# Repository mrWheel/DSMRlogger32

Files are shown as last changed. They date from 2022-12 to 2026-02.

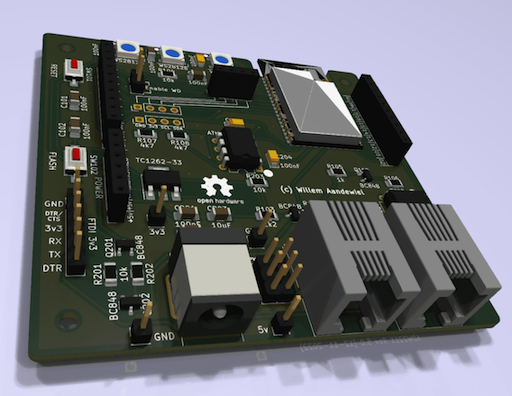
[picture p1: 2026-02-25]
DSMRlogger32/projectMetaData/DSMRlogger32.png

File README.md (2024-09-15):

# DSMRlogger32
Firmware for Rev. 5 of the DSMR-logger (Slimme Meter uitlezer)

This project is converted to VScode and PlatformIO.

# THIS IS A PRODUCTION RELEASE

This firmware is based on the **DSMRloggerAPI** (v3.0.4) firmware for the ESP8266 Micro Processor.

The **DSMRlogger32** firmware is for the **DSMR-logger32 Rev. 5** board with a ESP32 Micro Processor.

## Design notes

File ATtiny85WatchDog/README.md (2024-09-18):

# ATtiny85 Watch Dog for ESP8266/ESP32

## Overview

This project implements a watchdog functionality for any MCU using an ATtiny85 microcontroller. The watchdog monitors the main system (main MCU) for proper operation and can reset it if necessary.

## Hardware Configuration

The ATtiny85 is configured as follows:

```
ATMEL ATTINY85
                       +--\/--+
            RESET PB5 1|      |8 VCC
     <--[MCU_EN]  PB3 2|      |7 PB2  (INT0) <----- heartbeat
      [RESET_ME]  PB4 3|      |6 PB1  [x] 
                  GND 4|      |5 PB0  [NEO_LED] -> 
                       +------+
```

- PB0 (Pin 5): Connected to a NeoPixel LED for status indication
- PB2 (Pin 7): Receives heartbeat signals from the main system
- PB3 (Pin 2): Controls the main MCU's enable (reset) pin
- PB4 (Pin 3): Self-reset pin

## Programming

1.  First select [PROJECT TASKS] (the scary mask)
2.  Click on `set Fuses` (check that no errors occur)
3.  Now click on the [->] upload icon at the bottom of VSCode

## Functionality

The watchdog operates in several states, indicated by the NeoPixel LED:

1. **Power On**: Blue LED fades on and off for 30 seconds.
2. **Normal Operation**: Green LED heartbeat. Flashes bright when receiving heartbeat pulse from the main system.
3. **First Alarm**: Slow Red LED heartbeat if no heartbeats received for 60 seconds.
4. **Second Alarm**: Faster Red LED heartbeat if no heartbeats received for 75 seconds.
5. **Last Change**: Rapid Red LED blinking for 5 seconds before resetting the main system.
6. **Reset Master**: Bright White LED on while resetting the main system and waiting for it to restart.

## Key Features

- Uses interrupts to detect heartbeat signals from the main system.
- Implements a state machine for different levels of system monitoring.
- Utilizes a NeoPixel LED for visual status indication.
- Can reset both the main system MCU and itself if necessary.

## Configuration

The watchdog timing can be adjusted using the following constants:

- `_STARTUP_TIME`: 30 seconds
- `_MAX_NO_HARTBEAT`: 90 seconds (maximum time without a heartbeat before reset)
- `_LAST_WARNING`: 75 seconds (second alarm trigger)
- `_FIRST_WARNING`: 60 seconds (first alarm trigger)
- `_LAST_CHANGE`: 5 seconds (duration of last warning before reset)

## Usage

1. Connect the ATtiny85 to your main MCU system according to the pin configuration.
2. Program the ATtiny85 with this code.
3. Ensure your main system MCU sends regular heartbeat signals to the ATtiny85.
4. The watchdog will monitor your system and reset it if it becomes unresponsive.

## Dependencies

- EnableInterrupt library
- Custom NeoPixel library (neoPixStuff.h)

## License

This project is released under the MIT License. See the source code for full license text.

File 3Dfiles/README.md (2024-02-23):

# YAPP_Box
Yet Another Parametric Projectbox generator

This OpenSCAD project can be used to create extremely comprehensive and customizable project boxes/enclosures using OpenSCAD.

The [complete and official documentation gitbook](https://mrwheel-docs.gitbook.io/yappgenerator_en/) explains the entire API.

You can open Issues here, but please also place them in a comment at one of the following blog posts:
* "<a href="https://willem.aandewiel.nl/index.php/2022/01/02/yet-another-parametric-projectbox-generator/">Yet Another Parametric Projectbox generator blog post</a>" (English)
* "<a href="https://willem.aandewiel.nl/index.php/2022/01/01/nog-een-geparameteriseerde-projectbox-generator/">Nog een geparametriseerde projectbox generator</a>" (Dutch).

<hr>

I have done my best, but it can probably be done simpler. 
If you think you can help, please contact me or make a Pull Request.

## How to program your Project Box
It all starts with the dimensions of the PCB going inside your Project Box, as well as a few other dimensions:

```openscad
printBaseShell      = true;
printLidShell       = true;

// Edit these parameters for your own board dimensions
wallThickness       = 1.0;
basePlaneThickness  = 1.0;
lidPlaneThickness   = 1.0;

// Total height of box = basePlaneThickness + lidPlaneThickness 
//                     + baseWallHeight + lidWallHeight

baseWallHeight      = 7;
lidWallHeight       = 4;

pcbLength           = 88;
pcbWidth            = 49;
pcbThickness        = 1.5;
                            
// padding between pcb and inside wall
paddingFront        = 4;
paddingBack         = 1;
paddingRight        = 1;
paddingLeft         = 1;

// ridge where Base- and Lid- off the box can overlap
// Make sure this isn't less than lidWallHeight
ridgeHeight         = 3;
ridgeSlack          = 0.2;
roundRadius         = 2.0;  // don't make this to big..

//-- How much the PCB needs to be raised from the base
//-- to leave room for solderings and whatnot
standoffHeight      = 5.0;
pinDiameter         = 1.0;
pinHoleSlack        = 0.5;
standoffDiameter    = 4;
```

You probably want some cutouts in your box for connectors and stuff.
For every plane (side) of the Project Box, there is an array that holds the cutouts for that plane.

A picture is worth a thousand words ...

### Cutouts in the *Right* Plane:
YAPP_cutoutsRight

### Cutouts in the *Left* Plane:
YAPP_cutoutsLeft

### Cutouts in the *Back* Plane:
YAPP_cutoutsBack

### Cutouts in the *Front* Plane:
YAPP_cutoutsFront

### Cutouts in the *Base*:
YAPP_cutoutsBase

### Cutouts in the *Lid*:
YAPP_cutoutsLid

### Using the *angle* param (rotate around the x/y corner):
yappRectangle40dgrs

#### With `yappCenter`, the rectangle will rotate around its center point:
yappRectangleCenter10dgrs

### Base mounts:


### `pcbStands`:
`pcbStands` fixate the PCB between the base and the lid.
YAPP_pcbStands

### Connectors between *Base* and *Lid*:
YAPP_connectors

### ConnectorsPCB between *Base* and *Lid* that fixates the PCB:
connectorTypes

YAPP_connector_D

Inserts are great for making a screw connection between the base and the lid.
Ruthex-insert-a

### Snap Joins:
snapJoins1

snapJoins2

#### Snap Joins *Symmetrical*:
snapJoinsSymetric

### (more) Base Mounts:
yappBaseStand

yappBaseStand3D

### Hooks:
There are two type of "hooks"; at the inside of the box or at the outside of the box
#### `baseHookOutside()`:
baseHookOutside

baseHookOutside3D
#### `lidHookInside()`:
lidHooksInside1

lidHooksInside3Db

lidHooksInside3Da

<hr>

## Buy me a coffee (please)!

If you like this project or it saved you time, you can give me a cup of coffee :)

<p>
  <a href="https://www.paypal.me/WillemAandewiel/3">
      bmc-button-75
  </a>
</p>

## Versioning
* All major releases (v1, v2, v3) are intended to be compatible with all files previously designed for v3 (e.g., the v3.1 release will not remove features or make any breaking changes, compared to v3.0).
* The filename of the library (e.g., `YAPPgenerator_v3.scad`) will thus have only the major version in its filename.
* When a new major version is released, a branch will be created from the `main` branch at the last commit before work is started on the next major version. This branch can be used to fix bugs and add features to the old release version, if desired. These lineage branches will not be merged to `main`, and will continue on their own path.
* All future tagged versions will have GitHub Releases created for them, which will include the changelog for the release. The `YAPP_Template_vx.scad` and `YAPPgenerator_vx.scad` files will also be attached to the release.
* The ISO8601 international standard date format (yyyy-mm-dd) will be used for documenting dates.

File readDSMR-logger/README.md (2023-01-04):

# readDSMR-logger

Dit is een raamwerk om met verschillende MCU's de DSMRlogger32 uit te lezen en
de gegevens verder te verwerken.

Per board-type moet je één van onderstaande #define's actief maken door de twee 
slashes (//) ervoor weg te halen.
<pre>
//======= define type of board ===========
//==== only define one (1) board type ====
// #define _IS_ARDUINO_MEGA
// #define _IS_ESP8266
// #define _IS_ESP32
</pre>

### "myCredentials_org.h" 
Kopieer deze tab naar "myCredentials.h"

### In de tab "myCredentials.h" 
Define het IP address van jouw DSMR-logger:
<pre>
#define _DSMR_IP_ADDRESS    "IP_ADDRESS_OF_YOUR_DSMR_LOGGER"
</pre>

Als je een bordje met WiFi gebruikt voer dan hier de WiFi credentials van jouw AccessPoint in:
<pre>
#define _WIFI_SSID          "YOUR_WIFI_SSID"
#define _WIFI_PASSWRD       "YOUR_WIFI_PASSWRD"
</pre>

Dit programma vergt het maximale van een Arduino UNO met Ethernet shield!

Meer informatie over de DSMRlogger32 kun je 
<a href="https://willem.aandewiel.nl/index.php/2022/11/15/crisis-what-crisis/">hier</a>
vinden.

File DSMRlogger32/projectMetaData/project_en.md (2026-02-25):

# DSMRlogger32

This is an improved and more modern version of my earlier DSMR loggers (energy meter readers for smart meters).
Due to the energy crisis, it has become more important to monitor energy consumption closely. Therefore, after almost four years, I developed a new version.

The DSMRlogger32 offers the same basic functionality as the previous version, but operates more reliably and features improved memory management thanks to the ESP32 with PSRAM module. Some features from earlier versions have been removed (such as integration with mindergas.nl and an ADC interface), as they were considered non-essential.

New features include the ability to connect a shield with additional hardware (for example Modbus or relays), and a secondary P1 port for connecting an additional reader. In addition, a hardware watchdog has been added to prevent the system from locking up.

The project includes both hardware design and firmware, with improved support for JSON data and a more stable logging experience. PCBs or complete kits are available.

**Note!**
You can flash the firmware for the ESP32 here, but if you build the entire project yourself, please note that the ATtiny85 (watchdog) must also be flashed separately.

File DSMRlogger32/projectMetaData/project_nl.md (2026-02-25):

# DSMRlogger32

Dit is een verbeterde en modernere versie van mijn eerdere DSMR-loggers (energiemeteruitlezers voor slimme meters).
Door de energiecrisis is het belangrijker geworden om het energieverbruik goed bij te houden. Daarom heb ik na bijna vier jaar een nieuwe versie ontwikkeld.

De DSMRlogger32 biedt dezelfde basisfunctionaliteit als de vorige versie, maar werkt betrouwbaarder en beschikt over beter geheugenbeheer dankzij de ESP32 met PSRAM-module. Sommige functies uit eerdere versies zijn verwijderd (zoals integratie met mindergas.nl en een ADC-interface), omdat deze als niet-essentieel werden beschouwd.

Nieuwe kenmerken zijn onder andere de mogelijkheid om een shield met extra hardware aan te sluiten (bijvoorbeeld Modbus of relais), en een secundaire P1-poort om een extra uitlezer aan te sluiten. Daarnaast is een hardware-watchdog toegevoegd om vastlopen te voorkomen.

Het project omvat zowel hardwareontwerp als firmware, met verbeterde ondersteuning voor JSON-data en een stabielere loggingervaring. Er is de mogelijkheid om PCB’s of complete sets te verkrijgen.

Let op!
Je kunt hier de firmware voor de ESP32 flashen, maar als je het volledige project zelf bouwt, houd er dan rekening mee dat je de ATtiny85 (watchdog) ook zelf moet flashen.

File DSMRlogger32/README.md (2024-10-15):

# DSMRlogger32
Firmware for the DSMR-logger Rev. 5.0 using only API call's

[Here](https://willem.aandewiel.nl/index.php/2022/11/15/crisis-what-crisis/),
    [here](https://willem.aandewiel.nl/index.php/2019/04/09/dsmr-logger-v4-slimme-meter-uitlezer/) and
    [here](https://willem.aandewiel.nl/index.php/2020/02/28/restapis-zijn-hip-nieuwe-firmware-voor-de-dsmr-logger/)
          you can find information about this project.

Documentation can be found [here](https://mrwheel-docs.gitbook.io/dsmrlogger32/) (in progress)!

### Ported to PlatformIO
As of now the DSMRlogger32 firmware is ported to `VSCode` with the `PlatformIO` extension.
<p>

<table>
  <tr><th>Versie</th><th align="Left">Opmerking</th></tr>
  <tr>
    <td valign="top">5.4.2</td>
    <td>Nieuwe functionaliteit
        <br>2024-10-15: Add second relay on shield.<br>
        Ieder relay kan afzonderlijk binnen een tijdsframe worden in- en uitgeschakeld.<br>
        Het is het beste om zowel de firmware alsook SPIFFS te updaten.
    </td>
  </tr>
  <tr>
    <td valign="top">5.4.0</td>
    <td>Nieuwe functionaliteit
        <br>2024-10-03: Met deze update is het niet alleen mogelijk om firmware updates
        van de Remote Server te halen en te flashen maar ook het SPIFFS bestandsysteem
        kan nu via [Update Remote] worden geflashed.<br><br>
        Er is een nieuw soort presentatie met horizontale 'bars'. Dit is een voortborduring
        op de Gauges van HJM. Deze voldoen helaas niet bij installaties met zonnepanelen
        vandaar deze nieuwe functionaliteit. Je kunt deze zien door op het icoontje
        <big>&#9776</big> te klikken.<br>
        pwrBars
        <br><br>
        Om deze nieuwe update te kunnen gebruiken moet je éérst de firmware updaten en
        daarná het SPIFFS bestand systeem. Vergeet niet om je RING en `.json` bestanden
        te downloaden en na de update weer terug te zetten.
    </td>
  </tr>
  <tr>
    <td valign="top">5.3.0</td>
    <td>Nieuwe functionaliteit
        <br>2024-09-20: Firmware updates kunnen nu ook vanaf een remote server worden
        opgehaald. Als de functie wordt opgestart ([FSmanager]->[Update Remote])
        verschijnt er een scherm met een drop-down lijst met beschikbare updates.<br>
        Selecteer de gewenste update en klik op [Update] om de update uit te voeren
        of op [Return] om terug te keren naar de FSmanager.<br>
        Om deze nieuwe functionaliteit te kunnen gebruiken moet éénmalig de nieuwe
        firmware (versie 5.3.0) naar je lokale computer worden gedownload en daarna
        met [Update Local] worden geflashed.<br>
        Om deze functie te kunnen gebruiken moet, behalve de firmware update, ook
        het bestand `FSmanager.html` (te vinden op `github`) vanuit de data folder 
        worden gedownload naar je lokale computer en daarna met de FSmanager worden
         ge-[Upload].<br>
        Het uploaden van SPIFFS is helaas nog niet mogelijk.
    </td>
  </tr>
  <tr>
    <td valign="top">5.2.1</td>
    <td>Nieuwe functionaliteit
        <br>2024-09-16: Op een GPIO-pin kan (bijvoorbeeld) een relays worden aangesloten.
        Via de [Instellingen] -> [Systeem] kun je nu opgeven op welke GPIO-pin
        dit relays is aangesloten en bij welke waarden dit relays "Aan" of "Uit" moet 
        gaan. Om niet te snel na het "Uit" schakelen van het relays deze weer "Aan" 
        te zetten kan er een Hysterese Tijd worden ingesteld.<br>
        Ook kan de logica van de aansturing van het Relays ge-inverteerd
        worden (om te voorkomen dat het relays in rust, de "Uit stand", juist
        bekrachtigd wordt). Sommige relays modules maken gebruik van deze 
        inversed logic.
    </td>
  </tr>
  <tr>
    <td valign="top">5.0.5</td>
    <td>Nieuwe functionaliteit
        <br>24-04-2023: Uitbreiding "Actual Tabel" naar 500 punten.
        Hiervoor is ook DSMRgraphics.js aangepast
        <br>Het is nu mogelijk de DSMR-logger32 in zgn. "Access Point"
        mode op te starten. De DSMR-logger32 wordt dan zelf een Access
        Point waar je je computer of tablet aan kunt koppelen.
        <br>De GUI en telnet zijn daarna bereikbaar op IP Adres "192.168.4.1" of
        URL "DMSR-ESP32.local".
    </td>
  </tr>
  <tr>
    <td valign="top">5.0.4</td>
    <td>First Production Release
        <br>De API is aangepast en uitvoer ervan zal verschillen van die in de 
        DSMRloggerAPI firmware (Rev. 3).
    </td>
  </tr>
  <tr>
    <td valign="top">5.0.3</td>
    <td>Release Candidate
        <br>Mindergas functionaliteit is weggehaald, want hoort niet thuis in deze firmware.
        Je kunt eenvoudig met een los esp8266 bordje de gegevens uit deze DSMR-logger halen en
        naar 'mindergas' sturen.
        <br>De API is aangepast en uitvoer ervan zal verschillen van die in de 
        DSMRloggerAPI firmware (Rev. 3).
    </td>
  </tr>
  <tr>
    <td valign="top">5.0.0</td>
    <td>Not for production!
        <br>Deze firmware is bij-lange-na nog niet compleet of zelf "werkend"
        <br>Mindergas functionaliteit is weggehaald, want hoort niet thuis in deze firmware.
        Je kunt eenvoudig met een los esp8266 bordje de gegevens uit deze DSMR-logger halen en
        naar 'mindergas' sturen.
        <br>Waarschijnlijk wordt de API aangepast en zal dus verschillen van die in de 
        DSMRloggerAPI firmware (Rev. 3).
    </td>
  </tr>
</table>

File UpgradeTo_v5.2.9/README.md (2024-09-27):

# Upgrade DSMRlogger32 naar v5.2.9

Het programma `Upgrade_v5.2.9.py` wordt gebruikt om de firmware en het bestandssysteem van de DSMRlogger32 te *upgraden* naar **v5.2.9**.

## Waarom is dit nodig?

Vanaf **v5.2.9** (dat in feite een *dummy* versie is ter voorbereiding op **v5.3.0**) is het mogelijk om firmware-updates rechtstreeks van een **Remote Firmware Server** te verkrijgen. 

Dit heeft als voordeel dat je zelf geen ontwikkelomgeving hoeft op te zetten. De maintainer van de DSMRlogger32 zal de firmware-updates op zijn remote server plaatsen, waarna je jouw DSMRlogger32 eenvoudig kunt updaten.

Helaas zijn de firmwareversies van vóór v5.2.9 niet geschikt voor deze functionaliteit. Het is alleen mogelijk om de upgrade ***bedraad*** uit te voeren.
Vervolgens moet je eenmalig de stappen in deze handleiding volgen.

## Wat heb je nodig ##

Voor de upgrade heb je het programma `Upgrade_v5.2.9.py` nodig, dat is geschreven in Python. Als Python nog niet op je computer is geïnstalleerd, kun je het downloaden [via deze link](https://www.python.org/downloads/).

Daarnaast heb je een **FTDI**- of een **USB naar seriële**-kabel nodig om de DSMRlogger32 op je computer aan te sluiten. Er zijn verschillende kabels beschikbaar en de prijzen kunnen sterk variëren. Het is daarom verstandig om even onderzoek te doen naar welke kabel voor jou het meest geschikt is.

**Let er wél op dat het een bordje of kabel is voor 3.3 volt (3v3) anders kun je de DSMRlogger32 beschadigen.**
<table>
  <tr>
    <td></td>
    <td>FTDI kabel<br>Let erop dat de aansluitingen overeenkomen met die van de DSMRlogger32</td>
  </tr>
  <tr>
    <td>Kabel2 </td>
   <td>USB naar TTL-Seriële kabel<br>Vcc hoeft niet te worden aangesloten<br>Alleen GND, TX en RX aansluiten</td>
  </tr>
  <tr>
    <td>Kabel3 </td>
    <td>FTDI bordje<br>Let erop dat de aansluitingen overeenkomen met die van de DSMRlogger32</td>
  </tr>
</table>

Een FTDI **3v3** kabel of bordje is aanbevolen. Hiermee wordt de DSMRlogger32 automatisch in de juiste flash mode gezet door het programma `Upgrade_v5.2.9.py`. Als je een *FTDI*- of *USB naar TTL*-kabel gebruikt die dit niet automatisch doet, zoals *USB naar TTL*-kabels met drie of vier aansluitingen, kun je de volgende foutmelding krijgen:
```
DSMRlogger32_Flasher - INFO - Starting DSMRlogger32 flashing process on port: <COM PORT>>
DSMRlogger32_Flasher - INFO - Working directory: /Users/<you>/DSMRlogger32/UpgradeTo_v5.2.9
DSMRlogger32_Flasher - INFO - Executing esptool with arguments: /Users/<you>/esptool.py v4.5.1
Serial port <COM PORT>
Connecting......................................
A fatal error occurred: Failed to connect to ESP32: No serial data received.
For troubleshooting steps visit: https://docs.espressif.com/projects/esptool/en/latest/troubleshooting.html
returned non-zero exit status 2.
DSMRlogger32_Flasher - ERROR - Error flashing DSMRlogger32
DSMRlogger32_Flasher - INFO - DSMRlogger32 flashing process completed.
```
 Als je deze foutmelding krijgt, moet je handmatig de flash mode activeren door de knoppen op de DSMRlogger32 als volgt te gebruiken, voordat je het programma start:

1.  Druk op de [Flash] knop en hou deze ingedrukt
2.  Druk nu op de [Reset] knop en laat deze weer los
3.  Laat nu de [Flash] knop los.

Na deze stappen zou het programma de DSMRlogger32 moeten herkennen en starten met de firmware-upgrade.

## Hoe voer je de upgrade uit?

1. **Download het pakket**:
   - Download een **`.zip`** bestand van deze repository naar je computer of gebruik het volgende commando om de repository te *clonen*:
     ```bash
     git clone https://github.com/mrWheel/DSMRlogger32.git
     ```
   - Let op: alleen de map `UpgradeTo_v5.2.9` is relevant voor de upgrade.

2. **Volg deze stappen één voor één en in de juiste volgorde**:
   - Start de FSmanager (het icoon van het *Filing Cabinet*).
   - Download de drie `RING-bestanden` naar je computer.
   - Download eventueel het `DSMRdevSettings.json` bestand naar je computer.
   - Sluit de DSMRlogger32 nog niet aan op je computer.
   - Start een ***Command Window***.
   - Navigeer naar de map `UpgradeTo_v5.2.9` met het commando `cd`.
   - Voer het volgende commando in:
     ```bash
     python3 Upgrade_v5.2.9.py <COM PORT>
     ```
     Vervang `<COM PORT>` door de poort waarop de DSMRlogger32 is (of wordt) aangesloten.

     De uitvoer zou ongeveer als volgt moeten zijn:
```plaintext
python3 Upgrade_v5.2.9.py <COM PORT>
DSMRlogger32_Flasher - INFO - Starting DSMRlogger32 flashing process on port: <COM PORT>
...
DSMRlogger32_Flasher - INFO - Installing required packages...
Collecting esptool
  Downloading esptool-4.8.1.tar.gz (409 kB)
    ━━━━━━━━━━━━━━━━━━━━━━━━━━━━━━━━━━━━━━━━ 409.5/409.5 kB 2.1 MB/s eta 0:00:00
  Installing build dependencies ... done
  Getting requirements to build wheel ... done
  Preparing metadata (pyproject.toml) ... done
Collecting pyserial
  Using cached pyserial-3.5-py2.py3-none-any.whl.metadata (1.6 kB)
...
Using cached six-1.16.0-py2.py3-none-any.whl (11 kB)
Using cached pycparser-2.22-py3-none-any.whl (117 kB)
Building wheels for collected packages: esptool
  Building wheel for esptool (pyproject.toml) ... done
  Created wheel for esptool: filename=esptool-4.8.1-py3-none-any.whl size=534237 sha256=74561f52b0d9d75887e4777d962133ed23538191d27c84625cfc40554360ffcd
  Stored in directory: /Users/<you>>/Library/Caches/pip/wheels/0e/da/61/96ab0615cc87eb88b681fd147d47ec0c9954e1349e3ce19753
Successfully built esptool
Installing collected packages: reedsolo, pyserial, intelhex, bitarray, six, PyYAML, pycparser, bitstring, argcomplete, ecdsa, cffi, cryptography, esptool
Successfully installed PyYAML-6.0.2 argcomplete-3.5.0 bitarray-2.9.2 bitstring-4.2.3 cffi-1.17.1 cryptography-43.0.1 ecdsa-0.19.0 esptool-4.8.1 intelhex-2.3.0 pycparser-2.22 pyserial-3.5 reedsolo-1.7.0 six-1.16.0
...
2024-09-25 14:12:20,155 - DSMRlogger32_Flasher - ERROR - Error flashing DSMRlogger32: Command '...' returned non-zero exit status 2.
2024-09-25 14:12:20,155 - DSMRlogger32_Flasher - INFO - DSMRlogger32 flashing process completed.
```
     Het proces stopt hier omdat er geen communicatie met de DSMRlogger32 is.

   - Sluit nu de DSMRlogger32 aan op de gebruikte seriële poort.
   - Voer opnieuw het volgende commando in:
     ```bash
     python3 Upgrade_v5.2.9.py <COM PORT>
     ```
     De uitvoer zou er nu als volgt uit moeten zien:
```plaintext
python3 Upgrade_v5.2.9.py <COM PORT>
DSMRlogger32_Flasher - INFO - Starting DSMRlogger32 flashing process on port: <COM PORT>
...
DSMRlogger32_Flasher - INFO - Executing esptool with arguments: /Users/<you>/DSMRlogger32/UpgradeTo_v5.2.9/venv/bin/python -m esptool --chip esp32 --port <COM PORT> --baud 230400 --before default_reset --after hard_reset write_flash -z --flash_mode dio --flash_freq 80m --flash_size 4MB 0x1000 /Users/<you>/DSMRlogger32/UpgradeTo_v5.2.9/bootloader.bin 0x8000 /Users/<you>/DSMRlogger32/UpgradeTo_v5.2.9/partitions.bin 0x10000 /Users/<you>/DSMRlogger32/UpgradeTo_v5.2.9/firmware_v5.2.9.bin 0x310000 /Users/<you>/DSMRlogger32/UpgradeTo_v5.2.9/spiffs_v5.2.9.bin
esptool.py v4.5.1
Serial port <COM PORT>
Connecting....
Chip is ESP32-D0WD-V3 (revision v3.0)
Features: WiFi, BT, Dual Core, 240MHz, VRef calibration in efuse, Coding Scheme None
Crystal is 40MHz
MAC: 8c:4b:14:81:ff:e8
Uploading stub...
Running stub...
Stub running...
Changing baud rate to 230400
Changed.
Configuring flash size...
Flash will be erased from 0x00001000 to 0x00005fff...
Flash will be erased from 0x00008000 to 0x00008fff...
Flash will be erased from 0x00010000 to 0x0016efff...
Flash will be erased from 0x00310000 to 0x0038ffff...
Compressed 18992 bytes to 13110...
Wrote 18992 bytes (13110 compressed) at 0x00001000 in 0.9 seconds (effective 166.8 kbit/s)...
Hash of data verified.
Compressed 3072 bytes to 128...
Wrote 3072 bytes (128 compressed) at 0x00008000 in 0.1 seconds (effective 438.1 kbit/s)...
Hash of data verified.
Compressed 1436192 bytes to 884735...
Wrote 1436192 bytes (884735 compressed) at 0x00010000 in 43.4 seconds (effective 265.0 kbit/s)...
Hash of data verified.
Compressed 524288 bytes to 48967...
Wrote 524288 bytes (48967 compressed) at 0x00310000 in 4.1 seconds (effective 1014.0 kbit/s)...
Hash of data verified.

Leaving...
Hard resetting via RTS pin...
DSMRlogger32_Flasher - INFO - DSMRlogger32 flashed successfully!
DSMRlogger32_Flasher - INFO - DSMRlogger32 flashing process completed.
```
     De DSMRlogger32 zal nu opnieuw opstarten met de nieuwe firmware.

   - Upload de drie bewaarde `RING-bestanden`.
   - Upload eventueel het `DSMRdevSettings.json` bestand.
   - Reboot de DSMRlogger32.

## Controleer de nieuwe firmware

In de GUI kun je nu zien dat firmware versie v5.2.9 actief is.

GUI Versie

Om de nieuwe functionaliteit te testen, ga je terug naar de FSmanager.

FSmanager

Klik nu op de knop [Update Remote].<br>
In het scherm dat verschijnt, selecteer je de gewenste versie van de firmware.

Remote Update

(In dit geval **v5.3.0**), waarna je op [Update] klikt.

Wacht tot de DSMRlogger32 opnieuw is opgestart.

Wait a bit..

Controleer in de GUI of de juiste firmware nu actief is.

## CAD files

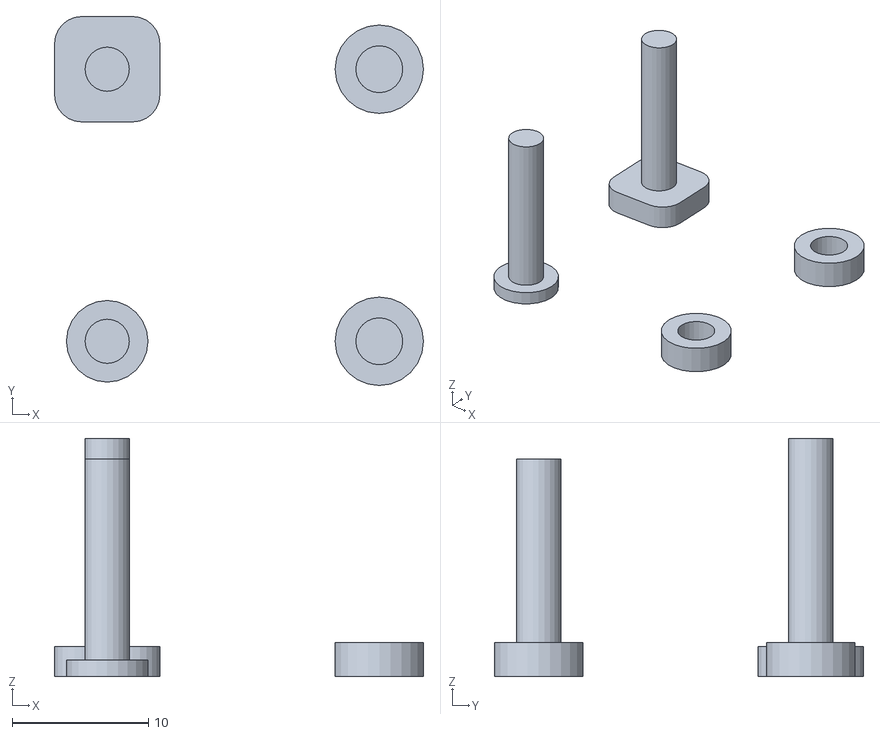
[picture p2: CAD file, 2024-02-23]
3Dfiles/STL/DSMR-logger32_R52_SwitchExtenders_v30.stl
27.1 x 27.1 x 17.5

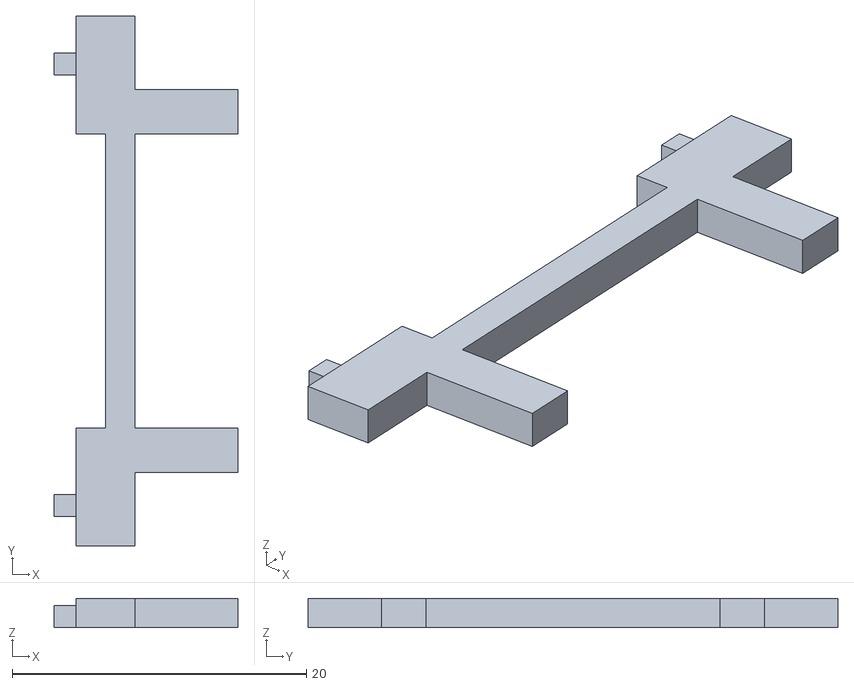
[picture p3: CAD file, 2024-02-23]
3Dfiles/STL/DSMR-logger32_R52_Stand_O13_v30.stl
12.5 x 36.0 x 2.00

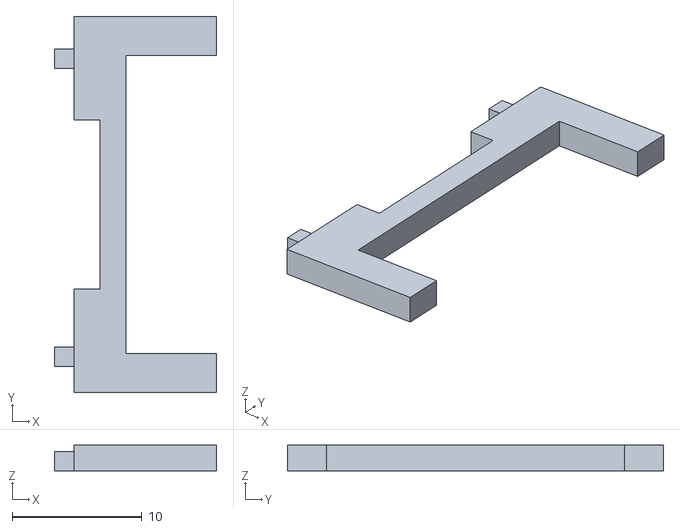
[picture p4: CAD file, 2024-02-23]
3Dfiles/STL/DSMR-logger32_R52_Stand_O09_v30.stl
12.5 x 29.0 x 2.00

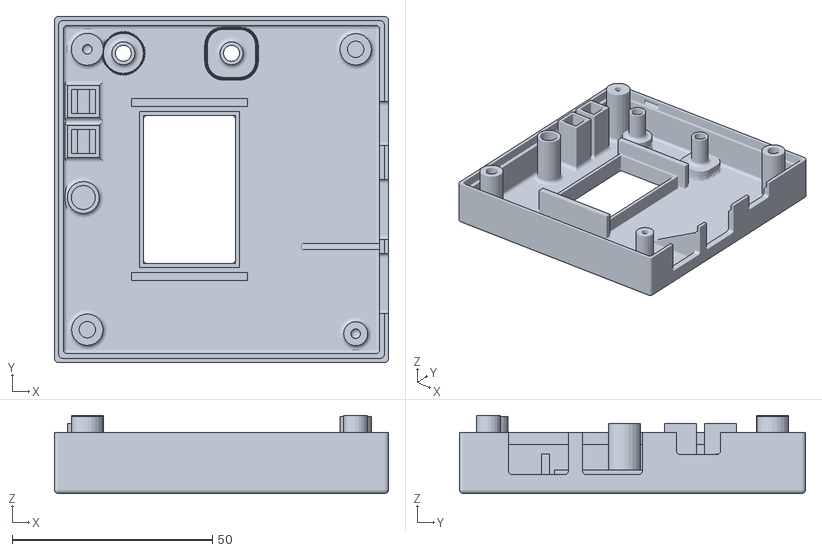
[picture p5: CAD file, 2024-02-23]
3Dfiles/STL/DSMR-logger32_R52_Top_O13_v30.stl
83.4 x 86.4 x 19.5

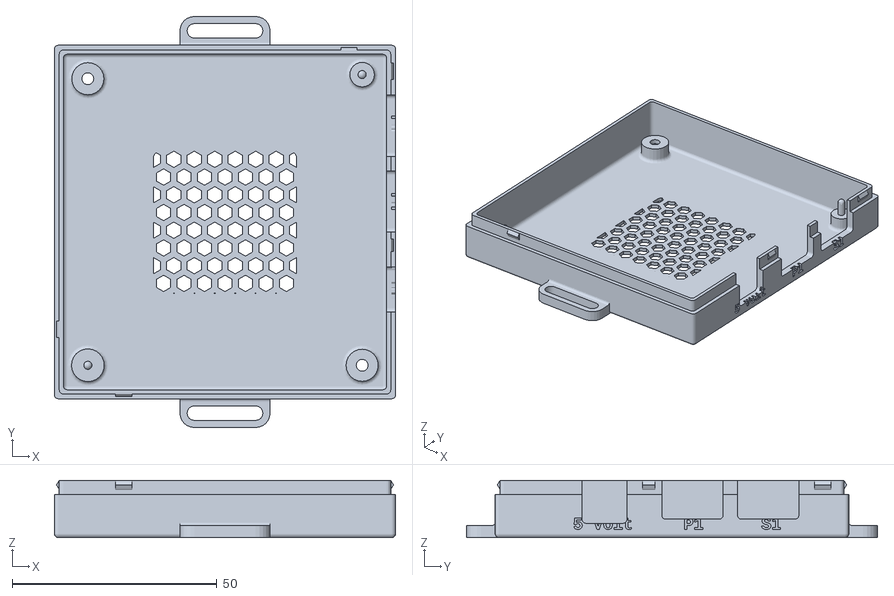
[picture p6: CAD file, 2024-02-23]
3Dfiles/STL/DSMR-logger32_R52_Base_v30.stl
83.4 x 100.4 x 14.0

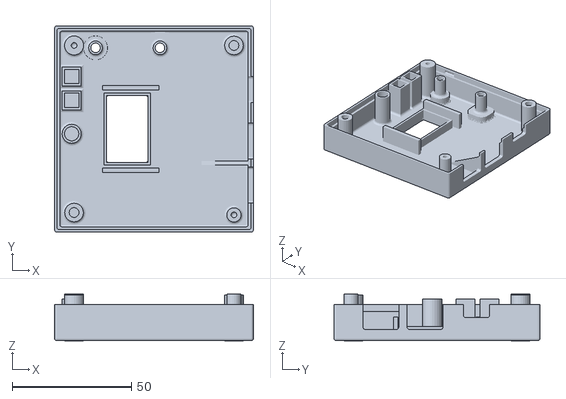
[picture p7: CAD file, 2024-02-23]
3Dfiles/STL/DSMR-logger32_R52_Top_O09_v30.stl
83.4 x 86.4 x 19.5

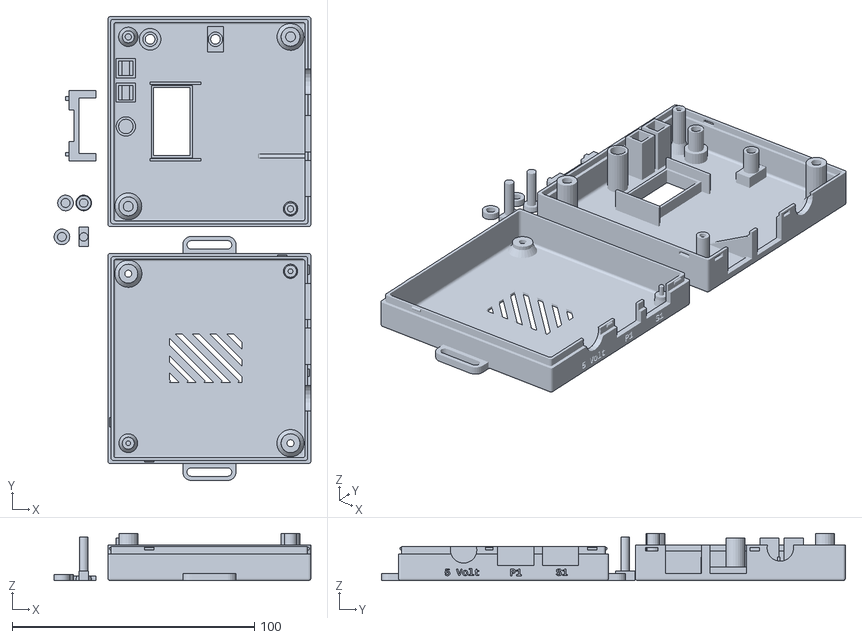
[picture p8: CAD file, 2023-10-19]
3Dfiles/STL/DSMR-logger32_R52_v20.stl
106.0 x 191.6 x 19.5

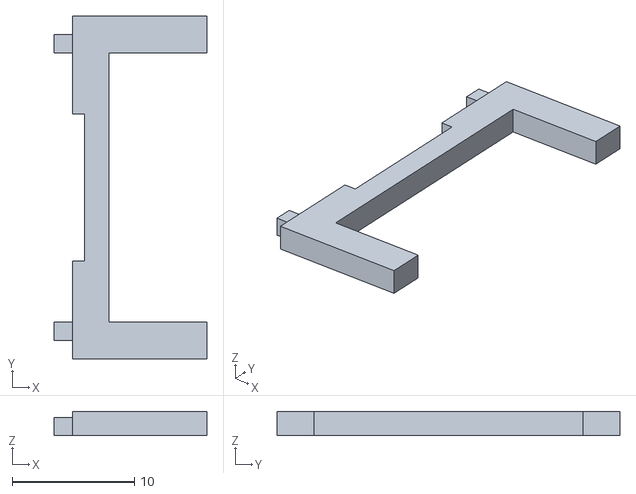
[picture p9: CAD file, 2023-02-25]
3Dfiles/STL/oled09Stand.stl
12.5 x 28.0 x 2.00

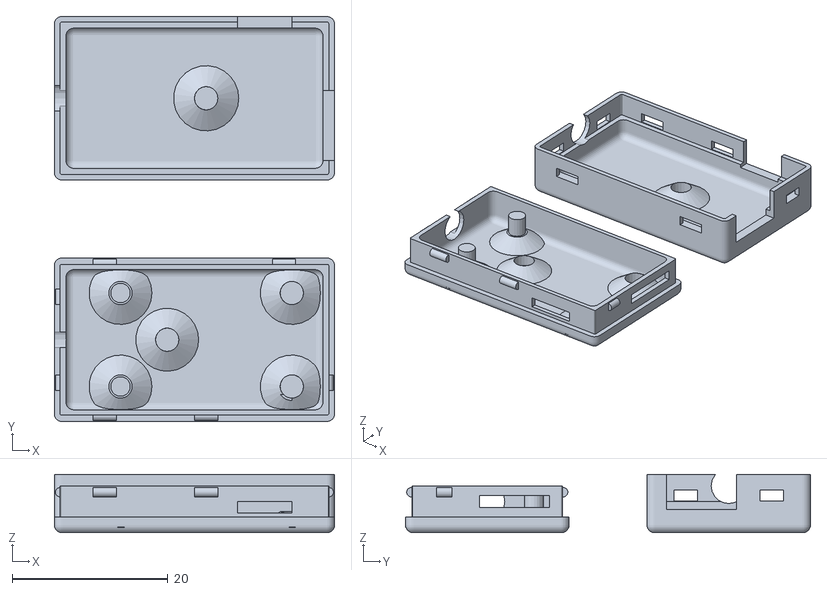
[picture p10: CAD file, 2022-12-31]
3Dfiles/STL/FTDIbox.stl
36.0 x 52.0 x 7.49

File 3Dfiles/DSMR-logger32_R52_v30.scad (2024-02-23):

//---------------------------------------------------------
// Yet Another Parameterized Projectbox generator
//
//  This is a box for a DSMR-logger32 v5.2 PCB
//  for use with the YAPP_generator_v30 lbrary
//
//  Version 3.0 (03-01-2024)
//
// This design is parameterized based on the size of a PCB.
//---------------------------------------------------------


//-- these parms need to be declared before including the YAPPgenerator
//
//-- is the filament transparent (true) or not (false)
//-- if (true) lightTubes will go all the way through the Lid
transparentFilament = true;  //-- {false|true}

//-- select oled size (both 'false' for none) -----
oled_09_inch          = false;
oled_13_inch          = true;

makeBaseShell        = false;
makeLidShell         = false;
makeSwitchExtenders  = false;
makeOledStand        = true;


if (oled_09_inch && oled_13_inch)
{
  for (i = [0 : 1 : 20])
  {
    echo("====================================");
    echo("Select (only one!) OLED screen size");
    echo("====================================");
  }
}
//
//- these dimensions are for a 1.3" OLED display
//-- oled dimensions and Header position
//                              //               V-------- HeaderY
oledHeader13X       = 16;       //       +~~~~~~~~~~~~~~~+            
oledHeader13Y       = 40;       //       |     ==o==     | HeaderX    ^
oledPcb13Width      = 37;       //       +---------------+ ScreenXs   |
oledPcb13Height     = 24;       //       |               |            |
oledScreen13Xs      =  3;       //       |               |            > Height
oledScreen13Xe      = 26;       //       |_______________|            |
                                //       +---------------+ ScreenXe   |
                                //       |               |            |
                                //       +---------------+            v
                                //       <--- Width ----->


//-- these dimensions are for a 0.9" OLED display
//-- oled dimensions and Header position
//                              //               V-------- HeaderY
oledHeader09X       = 17;       //       +~~~~~~~~~~~~~~~+            
oledHeader09Y       = 40;       //       |     ==o==     | HeaderX    ^
oledPcb09Width      = 28;       //       +---------------+ ScreenXs   |
oledPcb09Height     = 19;       //       |               |            |
oledScreen09Xs      =  1.5;     //       |               |            > Height
oledScreen09Xe      = 19.0;     //       |_______________|            |
                                //       +---------------+ ScreenXe   |
                                //       |               |            |
                                //       +---------------+            v
                                //       <--- Width ----->



oledScreen09Width  = oledPcb09Width;
oledScreen09Height = oledScreen09Xe - oledScreen09Xs;
oledScreen09X      = oledHeader09X + oledScreen09Xs;
oledScreen09Y      = oledHeader09Y - (oledScreen09Width/2);

oledScreen13Width  = oledPcb13Width;
oledScreen13Height = oledScreen13Xe - oledScreen13Xs;
oledScreen13X      = oledHeader13X + oledScreen13Xs;
oledScreen13Y      = oledHeader13Y - (oledScreen13Width/2);

//-- normalize params -----
oledHeaderX       = (oled_13_inch) ? oledHeader13X : oledHeader09X;
oledHeaderY       = (oled_13_inch) ? oledHeader13Y : oledHeader09Y;
oledScreenXs      = (oled_13_inch) ? oledScreen13Xs : oledScreen09Xs;
oledScreenXe      = (oled_13_inch) ? oledScreen13Xe : oledScreen09Xe;
oledScreenWidth   = (oled_13_inch) ? oledScreen13Width : oledScreen09Width;
oledScreenHeight  = (oled_13_inch) ? oledScreen13Height : oledScreen09Height;

oledRecess = (oled_09_inch || oled_13_inch) 
                      ? [oledScreenXs+oledHeaderX, oledHeaderY-(oledScreenWidth/2)
                         , oledScreenHeight, oledScreenWidth
                         , 1, -30003] //-> yappRoundedRect
                      : [];

lensThickness = (transparentFilament) ? 0.5 : 0;


include <./YAPPgenerator_v3.scad>

//include <./roundedCubes.scad>


/*
see https://polyd.com/en/conversione-step-to-stl-online
*/

myPcb = "./STL/MODELS/DSMR-logger32_MODEL_R52.stl";

if (true)
{
  translate([-47.3,-157.5,5.0]) 
  {
    rotate([0,0,90]) color("white") import(myPcb);
  }
}


// Note: length/lengte refers to X axis, 
//       width/breedte to Y, 
//       height/hoogte to Z

/*
      padding-back|<------pcb length --->|<padding-front
                            RIGHT
        0    X-as ---> 
        +----------------------------------------+   ---
        |                                        |    ^
        |                                        |   padding-right 
        |                                        |    v
        |    -5,y +----------------------+       |   ---              
 B    Y |         | 0,y              x,y |       |     ^              F
 A    - |         |                      |       |     |              R
 C    a |         |                      |       |     | pcb width    O
 K    s |         |                      |       |     |              N
        |         | 0,0              x,0 |       |     v              T
      ^ |   -5,0  +----------------------+       |   ---
      | |                                        |    padding-left
      0 +----------------------------------------+   ---
        0    X-as --->
                          LEFT
*/

printBaseShell        = makeBaseShell;
printLidShell         = makeLidShell;
printSwitchExtenders  = makeSwitchExtenders; 
//printInsideOLED       = makeInsideOled;  
printOledStand        = makeOledStand; 

// Edit these parameters for your own board dimensions
wallThickness       = 2.2; 
basePlaneThickness  = 1.0;
lidPlaneThickness   = 1.2;
// Set the ratio between the wall thickness and the ridge height. 
//    Recommended to be left at 1.8 but for strong snaps.
wallToRidgeRatio = 1.5;

//-- total height = 14 + pcbThickness + standoffHeight
//--         19.6 = 14 + 1.6 + 4
baseWallHeight      = 13; 
lidWallHeight       = 11; //-- was 8;

// ridge where base and lid off box can overlap
// Make sure this isn't less than lidWallHeight
ridgeHeight         = 3.5;
ridgeSlack          = 0.2;
roundRadius         = 1.0;

// How much the PCB needs to be raised from the base
// to leave room for solderings and whatnot
standoffHeight      = 4.0;  //-- only used to position PCB
standoffDiameter    = 5;
standoffPinDiameter = 2.0;
standoffHoleSlack   = 0.4;


// Total height of box = basePlaneThickness + lidPlaneThickness 
//                     + baseWallHeight + lidWallHeight
pcbLength           = 77;
pcbWidth            = 80;
pcbThickness        = 1.7;
                            
// padding between pcb and inside wall
paddingFront        = 1;
paddingBack         = 1;
paddingRight        = 1;
paddingLeft         = 1;


//---------------------------
//--     C O N T R O L     --
//---------------------------
// -- Render --
renderQuality             = 6;          //-> from 1 to 32, Default = 8
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

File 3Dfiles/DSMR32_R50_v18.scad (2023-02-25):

//---------------------------------------------------------
// Yet Another Parameterized Projectbox generator
//
//  This is a box for a DSMRlogger32 v5.x PCB
//
//  Version 1.0 (25-02-2023)
//
// This design is parameterized based on the size of a PCB.
//---------------------------------------------------------


//-- these parms need to be declared before including the YAPPgenerator

//-- default is 0.9" oled -----
oled_13_inch          = true;

//
//- these dimensions are for a 1.3" OLED display
//-- oled dimensions and Header position
//                              //               V-------- HeaderY
oledHeader13X       = 16;       //       +~~~~~~~~~~~~~~~+            
oledHeader13Y       = 40;       //       |     ==o==     | HeaderX    ^
oledPcb13Width      = 37;       //       +---------------+ ScreenXs   |
oledPcb13Height     = 24;       //       |               |            |
oledScreen13Xs      =  3;       //       |               |            > Height
oledScreen13Xe      = 26;       //       |_______________|            |
                                //       +---------------+ ScreenXe   |
                                //       |               |            |
                                //       +---------------+            v
                                //       <--- Width ----->


//-- these dimensions are for a 0.9" OLED display
//-- oled dimensions and Header position
//                              //               V-------- HeaderY
oledHeader09X       = 16;       //       +~~~~~~~~~~~~~~~+            
oledHeader09Y       = 40;       //       |     ==o==     | HeaderX    ^
oledPcb09Width      = 28;       //       +---------------+ ScreenXs   |
oledPcb09Height     = 19;       //       |               |            |
oledScreen09Xs      =  3;       //       |               |            > Height
oledScreen09Xe      = 16;       //       |_______________|            |
                                //       +---------------+ ScreenXe   |
                                //       |               |            |
                                //       +---------------+            v
                                //       <--- Width ----->



oledScreen09Width  = oledPcb09Width;
oledScreen09Height = oledScreen09Xe - oledScreen09Xs;
oledScreen09X      = oledHeader09X + oledScreen09Xs;
oledScreen09Y      = oledHeader09Y - (oledScreen09Width/2);

oledScreen13Width  = oledPcb13Width;
oledScreen13Height = oledScreen13Xe - oledScreen13Xs;
oledScreen13X      = oledHeader13X + oledScreen13Xs;
oledScreen13Y      = oledHeader13Y - (oledScreen13Width/2);

//-- normalize params -----
oledHeaderX       = (oled_13_inch) ? oledHeader13X : oledHeader09X;
oledHeaderY       = (oled_13_inch) ? oledHeader13Y : oledHeader09Y;
oledScreenXs      = (oled_13_inch) ? oledScreen13Xs : oledScreen09Xs;
oledScreenXe      = (oled_13_inch) ? oledScreen13Xe : oledScreen09Xe;
oledScreenWidth   = (oled_13_inch) ? oledScreen13Width : oledScreen09Width;
oledScreenHeight  = (oled_13_inch) ? oledScreen13Height : oledScreen09Height;

insertDiam  = 3.9;
screwDiam   = 2.7;
holeSlack   = 0.5;
insertDiamS = insertDiam + holeSlack;
screwDiamS  = screwDiam + holeSlack;


include <./YAPP_Box/library/YAPPgenerator_v18.scad>

include <./YAPP_Box/library/roundedCubes.scad>


/*
see https://polyd.com/en/conversione-step-to-stl-online
*/

myPcb = "./STL/DSMRloggerESP32_PCB_R50.stl";

if (false)
{
  translate([42,43,4.6]) 
  {
    rotate([0,0,90]) color("white") import(myPcb);
  }
}


// Note: length/lengte refers to X axis, 
//       width/breedte to Y, 
//       height/hoogte to Z

/*
      padding-back|<------pcb length --->|<padding-front
                            RIGHT
        0    X-as ---> 
        +----------------------------------------+   ---
        |                                        |    ^
        |                                        |   padding-right 
        |                                        |    v
        |    -5,y +----------------------+       |   ---              
 B    Y |         | 0,y              x,y |       |     ^              F
 A    - |         |                      |       |     |              R
 C    a |         |                      |       |     | pcb width    O
 K    s |         |                      |       |     |              N
        |         | 0,0              x,0 |       |     v              T
      ^ |   -5,0  +----------------------+       |   ---
      | |                                        |    padding-left
      0 +----------------------------------------+   ---
        0    X-as --->
                          LEFT
*/

printBaseShell        = false;
printLidShell         = false;
printSwitchExtenders  = false;
printInsideOLED       = false;
printOledStand        = true;
printSwitchCap        = false;

// Edit these parameters for your own board dimensions
wallThickness       = 2.4;
basePlaneThickness  = 1.0;
lidPlaneThickness   = 1.2;

//-- total height = 14 + pcbThickness + standoffHeight
//--         19.6 = 14 + 1.6 + 4
baseWallHeight      = 13; 
lidWallHeight       =  8;

// ridge where base and lid off box can overlap
// Make sure this isn't less than lidWallHeight
ridgeHeight         = 3;
ridgeSlack          = 0.2;
roundRadius         = 1.0;

// How much the PCB needs to be raised from the base
// to leave room for solderings and whatnot
standoffHeight      = 4.0;
pinDiameter         = 2.5;
pinHoleSlack        = 0.3;
standoffDiameter    = 6;

// Total height of box = basePlaneThickness + lidPlaneThickness 
//                     + baseWallHeight + lidWallHeight
pcbLength           = 77;
pcbWidth            = 80;
pcbThickness        = 1.6;
                            
// padding between pcb and inside wall
paddingFront        = 1;
paddingBack         = 1;
paddingRight        = 1;
paddingLeft         = 1;


//-- D E B U G -------------------
showSideBySide      = true;
hideLidWalls        = false;
onLidGap            = 0;
shiftLid            = 4;
colorLid            = "yellow";
hideBaseWalls       = false;
colorBase           = "white";
showOrientation     = true;
showPCB             = false;
showMarkers         = false;
inspectX            = 0;  // 0=none, >0 from front, <0 from back
inspectY            = 0;  // 0=none, >0 from left, <0 from right


//-- pcb_standoffs  -- origin is pcb[0,0,0]
// (0) = posx
// (1) = posy
// (2) = standoffHeight
// (3) = flangeHeight
// (4) = flangeDiam
// (5) = { yappBoth | yappLidOnly | yappBaseOnly }
// (6) = { yappHole, YappPin }
// (7) = { yappAllCorners | yappFrontLeft | yappFrondRight | yappBackLeft | yappBackRight }
pcbStands = [
            ];     

//-- Lid plane    -- origin is pcb[0,0,0]
// (0) = posx
// (1) = posy
// (2) = width
// (3) = length
// (4) = angle
// (5) = { yappRectangle | yappCircle }
// (6) = { yappCenter }
cutoutsLid =  [
      [14, 6,  6.5, 6.5, 0, yappCircle, yappCenter]         // Reset Button
     ,[41, 6,  8, 8, 0, yappRectangle, yappCenter]      // Flash Button
     //-- if no oled screen make next array a comment ---
     ,[oledScreenXs+oledHeaderX, oledHeaderY-(oledScreenWidth/2)
                        , oledScreenWidth, oledScreenHeight
                        , 0, yappRectangle]  // OLED
     ,[4, 18, 6, 6, 0, yappRectangle, yappCenter]       // NeoPixel 1
     ,[4, 28, 6, 6, 0, yappRectangle, yappCenter]       // NeoPixel 2
     ,[4, 40, 6, 6, 0, yappCircle]                      // NeoPixel 3
     ,[pcbLength-16, 40.5, 14, 18, 0,  yappRectangle]   // RJ12
     ,[pcbLength-16, 56.5, 14, 18, 0,  yappRectangle]   // RJ12
              ];

//-- base plane    -- origin is pcb[0,0,0]
// (0) = posx
// (1) = posy
// (2) = width
// (3) = length
// (4) = angle
// (5) = { yappRectangle | yappCircle }
// (6) = { yappCenter }
cutoutsBase =   [];

//-- cutoutGrills    -- origin is pcb[x0,y0,zx]
// (0) = xPos
// (1) = yPos
// (2) = grillWidth
// (3) = grillLength
// (4) = gWidth
// (5) = gSpace
// (6) = gAngle
// (7) = plane {"base" | "lid" }
// (8) = {polygon points}}

cutoutsGrill = [
                 [22, 30, 20, 30, 2, 3,  45, "base"]
               ];
              
//-- front plane  -- origin is pcb[0,0,0]
// (0) = posy
// (1) = posz
// (2) = width
// (3) = height
// (4) = angle
// (5) = { yappRectangle | yappCircle }
// (6) = { yappCenter }
cutoutsFront =  [
                    [40.5, -0.5, 14, 17, 0, yappRectangle]  // RJ11
                  , [56.5, -0.5, 14, 17, 0, yappRectangle]  // RJ11
                  , [24.5,  6,   12, 12, 0, yappCircle]     // PWR Jack

                ];

//-- back plane  -- origin is pcb[0,0,0]
// (0) = posy
// (1) = posz
// (2) = width
// (3) = height
// (4) = angle
// (5) = { yappRectangle | yappCircle }
// (6) = { yappCenter }
cutoutsBack =   [
                ];

//-- left plane   -- origin is pcb[0,0,0]
// (0) = posx
// (1) = posz
// (2) = width
// (3) = height
// (4) = angle
// (5) = { yappRectangle | yappCircle }
// (6) = { yappCenter }
cutoutsLeft =   [
                ];
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

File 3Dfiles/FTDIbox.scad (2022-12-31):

//-----------------------------------------------------------------------
// Yet Another Parameterized Projectbox generator
//
//  This is a box for FTDIbox
//
//  Version 1.1 (08-12-2022)
//
// This design is parameterized based on the size of a PCB.
//
//  for many or complex cutoutGrills you might need to adjust
//  the number of elements:
//
//      Preferences->Advanced->Turn of rendering at 100000 elements
//                                                  ^^^^^^
//
//-----------------------------------------------------------------------


include <../YAPP_Box/library/YAPPgenerator_v16.scad>

// Note: length/lengte refers to X axis, 
//       width/breedte to Y, 
//       height/hoogte to Z

/*
            padding-back>|<---- pcb length ---->|<padding-front
                                 RIGHT
                   0    X-ax ---> 
               +----------------------------------------+   ---
               |                                        |    ^
               |                                        |   padding-right 
             ^ |                                        |    v
             | |    -5,y +----------------------+       |   ---              
        B    Y |         | 0,y              x,y |       |     ^              F
        A    - |         |                      |       |     |              R
        C    a |         |                      |       |     | pcb width    O
        K    x |         |                      |       |     |              N
               |         | 0,0              x,0 |       |     v              T
               |   -5,0  +----------------------+       |   ---
               |                                        |    padding-left
             0 +----------------------------------------+   ---
               0    X-ax --->
                                 LEFT
*/

printBaseShell      = true;
printLidShell       = true;

// Edit these parameters for your own board dimensions
wallThickness       = 1.5;
basePlaneThickness  = 1.0;
lidPlaneThickness   = 1.0;

baseWallHeight      =  5;
lidWallHeight       =  3;

// ridge where base and lid off box can overlap
// Make sure this isn't less than lidWallHeight
ridgeHeight         = 4;
ridgeSlack          = 0.2;
roundRadius         = 1.0;

// How much the PCB needs to be raised from the base
// to leave room for solderings and whatnot
standoffHeight      = 0.5;
pinDiameter         = 2.5;
pinHoleSlack        = 0.3;
standoffDiameter    = 3;

// Total height of box = basePlaneThickness + lidPlaneThickness 
//                     + baseWallHeight + lidWallHeight
pcbLength           = 25;
pcbWidth            = 16;
pcbThickness        = 1.5;
                            
// padding between pcb and inside wall
paddingFront        = 3;
paddingBack         = 5;
paddingRight        = 1;
paddingLeft         = 1;


//-- D E B U G -------------------
showSideBySide      = true;
hideLidWalls        = false;
onLidGap            = 4;
shiftLid            = 0;
colorLid            = "yellow";
hideBaseWalls       = false;
colorBase           = "white";
showPCB             = false;
showMarkers         = false;
inspectX            = 0;  // 0=none, >0 from front, <0 from back
inspectY            = 0;  // 0=none, >0 from left, <0 from right


//-- pcb_standoffs  -- origin is pcb[0,0,0]
// (0) = posx
// (1) = posy
// (2) = { yappBoth | yappLidOnly | yappBaseOnly }
// (3) = { yappHole, YappPin }
pcbStands = [
                [ 2,  2, yappBaseOnly, yappPin] 
              , [ 2, 14, yappBaseOnly, yappPin] 
              , [ 8,  8, yappBaseOnly, yappHole] 
              , [24,  2, yappBaseOnly, yappHole] 
              , [24, 14, yappBaseOnly, yappHole] 
              , [13,  8, yappLidOnly,  yappHole] 
             ];     

//-- Lid plane    -- origin is pcb[0,0,0]
// (0) = posx
// (1) = posy
// (2) = width
// (3) = length
// (4) = angle
// (5) = { yappRectangle | yappCircle }
// (6) = { yappCenter }
cutoutsLid =  [
              ];

//-- base plane    -- origin is pcb[0,0,0]
// (0) = posx
// (1) = posy
// (2) = width
// (3) = length
// (4) = angle
// (5) = { yappRectangle | yappCircle }
// (6) = { yappCenter }
cutoutsBase =   [
                ];

//-- front plane  -- origin is pcb[0,0,0]
// (0) = posy
// (1) = posz
// (2) = width
// (3) = height
// (4) = angle
// (5) = { yappRectangle | yappCircle }
// (6) = { yappCenter }
cutoutsFront =  [
                    [11.5, -0.5, 9, 6, 0, yappRectangle, yappCenter]  // USB
                ];

//-- back plane  -- origin is pcb[0,0,0]
// (0) = posy
// (1) = posz
// (2) = width
// (3) = height
// (4) = angle
// (5) = { yappRectangle | yappCircle }
// (6) = { yappCenter }
cutoutsBack =   [
                  [8, 1, 4.5, 0, 0, yappCircle]      // cable
                ];

//-- left plane   -- origin is pcb[0,0,0]
// (0) = posx
// (1) = posz
// (2) = width
// (3) = height
// (4) = angle
// (5) = { yappRectangle | yappCircle }
// (6) = { yappCenter }
cutoutsLeft =   [
                    [17, -0.5, 7, 4, 0, yappRectangle]   // switch
                ];

//-- right plane   -- origin is pcb[0,0,0]
// (0) = posx
// (1) = posz
// (2) = width
// (3) = height
// (4) = angle
// (5) = { yappRectangle | yappCircle }
// (6) = { yappCenter }
cutoutsRight =  [
                ];

//-- cutoutGrills    -- origin is pcb[x0,y0, zx]
// (0) = xPos
// (1) = yPos
// (2) = grillWidth
// (3) = grillLength
// (4) = gWidth
// (5) = gSpace
// (6) = gAngle
// (7) = plane {"base" | "lid" }
// (8) = {polygon points}}

cutoutsGrill = [
               ];

//-- connectors -- origen = box[0,0,0]
// (0) = posx
// (1) = posy
// (2) = screwDiameter
// (3) = insertDiameter
// (4) = outsideDiameter
// (5) = { yappAllCorners }
connectors   =  [
                ];
                
//-- connectorsPCB -- origin = pcb[0,0,0]
//-- a connector that allows to screw base and lid together through holes in the PCB
// (0) = posx
// (1) = posy
// (2) = screwDiameter
// (3) = insertDiameter
// (4) = outsideDiameter
// (5) = { yappAllCorners }
connectorsPCB   =  [
                ];

//-- base mounts -- origen = box[x0,y0]
// (0) = posx | posy
// (1) = screwDiameter
// (2) = width
// (3) = height
// (4..7) = yappLeft / yappRight / yappFront / yappBack (one or more)
// (5) = { yappCenter }
baseMounts   = [
               ];
               
//-- snap Joins -- origen = box[x0,y0]
// (0) = posx | posy
// (1) = width
// (2..5) = yappLeft / yappRight / yappFront / yappBack (one or more)
// (n) = { yappSymmetric }
snapJoins   =     [
                    [5,  3, yappRight, yappSymmetric]
                  , [18, 3, yappLeft]
                  , [5,  3, yappLeft]
                  , [4,  2, yappFront]
                  , [4,  2, yappBack, yappSymmetric]
                ];
               
//-- origin of labels is box [0,0,0]
// (0) = posx
// (1) = posy/z
// (2) = orientation
// (3) = plane {lid | base | left | right | front | back }
// (4) = font
// (5) = size
// (6) = "label text"
labelsPlane =  [
                    [10,  10,   0, "lid",   "Liberation Mono:style=bold", 7, "YAPP" ]
               ];
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

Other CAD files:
3Dfiles/STL/DSMR-logger32_R52_Top_No_v30.stl
3Dfiles/roundedCubes.scad
3Dfiles/DSMR-logger32_R52_v20.scad
3Dfiles/YAPPgenerator_v20.scad
3Dfiles/YAPPgenerator_v3.scad

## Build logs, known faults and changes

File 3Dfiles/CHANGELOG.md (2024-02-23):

# YAPP Change Log

## Rev. v3.0.1 (2024-01-15)
* Re-organzie Git repo to maintain only the latest version in the `main` branch.
* The core files (`YAPP_Template_v3.scad`, `YAPPgenerator_v3.scad`) now keep only a major version in their filename, and live in the root of the repo.

## Rev. 3.0.0  (2023-12-01)

Lead Developer for v3.0: <a href="https://github.com/rosenhauer">Dave Rosenhauer</a>
Dave added new functionality, fixed many bugs, is the creator of the v3.0 API and did a lot of code cleanup.
He made more than 20 merge requests in three weeks.

**New functionality**
<pre>
Cutout Shapes
	Cutouts now support more shapes.
		yappRectangle	    : Rectangle with size 'width' x 'length' 
		yappCircle	    : Circle with radius of 'radius'
		yappRoundedRect	    : Rectangle with size 'width' x 'length' and corner 
                                      radius of 'radius'
		yappPolygon	    : User defined polygon. Three standard shapes are 
                                      included for use/reference - 'shapeIsoTriangle', 
                                      'shapeHexagon', 'shape6ptStar' 
		yappCircleWithFlats : Circle with radius of 'radius' with the sides 
                                      clipped to width (length is not used)
    		yappCircleWithKey   : Circle with radius of 'radius' with a rectangular 
                                      key of width x length (length is key depth)

Cutout Masks

Fillets
	Fillets are automatically added to all appropriate items.  
	This can be overridden with the yappNoFillet option.  
	Fillet radius can also be changed from default (same as connected wall thickness) 
	with the filletRadius parameter.

Ridge Extension
  Extension from the lid into the case for adding split opening at various heights

//========= HOOK dummy functions ============================
  
// Hook functions allow you to add 3d objects to the case.
// Lid/Base = Shell part to attach the object to.
// Inside/Outside = Join the object from the midpoint of the shell to the inside/outside.

//===========================================================
// origin = box(0,0,0)
module hookLidInside()
{
} // hookLidInside()
  
//===========================================================
// origin = box(0,0,shellHeight)
module hookLidOutside()
{
} // hookLidOutside()

//===========================================================
// origin = box(0,0,0)
module hookBaseInside()
{
} // hookBaseInside()

//===========================================================
// origin = box(0,0,0)
module hookBaseOutside()
{
} // hookBaseOutside()

//===========================================================
//===========================================================
</pre>

**Updated definition standards:**
<pre>
     Parameters:
	p(0,1 ...) = a 'p' with a number between parentheses indicates a 
	                    'positional' parameter.
	n(a,b ...) = a 'n' with a letter between parentheses indicates an 
	                    optional, 'non-positional' parameter must be after 
	                    the required parameters.
	{ yappParameter }
	&lt;Default value&gt;
	| means one or more values from the list are allowed
	, means only one value from the list is allowed
</pre>

**This version breaks with the API for the following objects:**

<pre>
===================================================================
  *** PCB Supports ***
  Pin and Socket standoffs 
-------------------------------------------------------------------
Default origin =  yappCoordPCB : pcb[0,0,0]

Parameters:
 Required:
  p(0) = posx
  p(1) = posy
 Optional:
  p(2) = Height to bottom of PCB : Default = defaultStandoffHeight
  p(3) = standoffDiameter    = defaultStandoffDiameter;
  p(4) = standoffPinDiameter = defaultStandoffPinDiameter;
  p(5) = standoffHoleSlack   = defaultStandoffHoleSlack;
  p(6) = filletRadius (0 = auto size)
  n(a) = { &lt;yappBoth&gt; | yappLidOnly | yappBaseOnly }
  n(b) = { &lt;yappPin&gt;, yappHole } : Baseplate support treatment
  n(c) = { &lt;yappAllCorners&gt; | yappFrontLeft | yappFrontRight | yappBackLeft | yappBackRight }
  n(d) = { &lt;yappCoordPCB&gt;, yappCoordBox }  
  n(e) = { yappNoFillet }
</pre>

<pre>
===================================================================
  *** Connectors ***
  Standoffs with hole through base and socket in lid for screw type connections.
-------------------------------------------------------------------
Default origin = yappCoordBox: box[0,0,0]
  
Parameters:
 Required:
  p(0) = posx
  p(1) = posy
  p(2) = pcbStandHeight
  p(3) = screwDiameter
  p(4) = screwHeadDiameter : (don't forget to add extra for the fillet)
  p(5) = insertDiameter
  p(6) = outsideDiameter
 Optional:
  p(7) = filletRadius : Default = 0/Auto(0 = auto size)
  n(a) = { &lt;yappAllCorners&gt; | yappFrontLeft | yappFrontRight | yappBackLeft | yappBackRight }
  n(b) = { &lt;yappCoordBox&gt;, yappCoordPCB }
  n(c) = { yappNoFillet }
</pre>

<pre>
===================================================================
  *** Base Mounts ***
  Mounting tabs on the outside of the box
-------------------------------------------------------------------
Default origin = yappCoordBox: box[0,0,0]

Parameters:
 Required:
  p(0) = pos
  p(1) = screwDiameter
  p(2) = width
  p(3) = height
 Optional:
  p(4) = filletRadius : Default = 0/Auto(0 = auto size)
  n(a) = { yappLeft | yappRight | yappFront | yappBack } : (one or more)
  n(b) = { yappNoFillet }
</pre>

<pre>
===================================================================
  *** Cutouts ***
  There are 6 cutouts one for each surface:
    cutoutsBase, cutoutsLid, cutoutsFront, cutoutsBack, cutoutsLeft, cutoutsRight
-------------------------------------------------------------------
Default origin = yappCoordBox: box[0,0,0]

                      Required                Not Used        Note
--------------------+-----------------------+---------------+------------------------------------
yappRectangle       | width, length         | radius        |
yappCircle          | radius                | width, length |
yappRoundedRect     | width, length, radius |               |     
yappCircleWithFlats | width, radius         | length        | length=distance between flats
yappCircleWithKey   | width, length, radius |               | width = key width length=key depth
yappPolygon         | width, length         | radius        | yappPolygonDef object must be provided
--------------------+-----------------------+---------------+------------------------------------

Parameters:
 Required:
  p(0) = from Back
  p(1) = from Left
  p(2) = width
  p(3) = length
  p(4) = radius
  p(5) = shape : {yappRectangle | yappCircle | yappPolygon | yappRoundedRect 
	         | yappCircleWithFlats | yappCircleWithKey}
 Optional:
  p(6) = depth : Default = 0/Auto : 0 = Auto (plane thickness)
  p(7) = angle : Default = 0
  n(a) = { yappPolygonDef } : Required if shape = yappPolygon specified -
  n(b) = { yappMaskDef } : If a yappMaskDef object is added it will be used as a mask for the cutout.
  n(c) = { &lt;yappCoordBox&gt;, yappCoordPCB }
  n(d) = { &lt;yappOrigin&gt;, yappCenter }
  n(e) = { &lt;yappGlobalOrigin&gt;, yappLeftOrigin } : Only affects Top, Back and Right Faces
</pre>

<pre>
===================================================================
  *** Snap Joins ***
-------------------------------------------------------------------
Default origin = yappCoordBox: box[0,0,0]

Parameters:
 Required:
  p(0) = posx | posy
  p(1) = width
  p(2) = { yappLeft | yappRight | yappFront | yappBack } : (one or more)
 Optional:
  n(a) = { &lt;yappOrigin&gt;, yappCenter }
  n(b) = { yappSymmetric }
  n(c) = { yappRectangle } == Make a diamond shape snap
</pre>

<pre>
===================================================================
  *** Light Tubes ***
-------------------------------------------------------------------
Default origin = yappCoordPCB: PCB[0,0,0]

Parameters:
 Required:
  p(0) = posx
  p(1) = posy
  p(2) = tubeLength
  p(3) = tubeWidth
  p(4) = tubeWall
  p(5) = gapAbovePcb
  p(6) = { yappCircle|yappRectangle } : tubeType
 Optional:
  p(7) = lensThickness : (how much to leave on the top of the lid for the light 
	 to shine through 0 for open hole, Default = 0/Open
  p(8) = Height to top of PCB : Default = defaultStandoffHeight+pcbThickness
  p(9) = filletRadius : Default = 0/Auto 
  n(a) = { &lt;yappCoordPCB&gt;, yappCoordBox }
  n(b) = { yappNoFillet }
</pre>

<pre>
===================================================================
  *** Push Buttons ***
-------------------------------------------------------------------
Default origin = yappCoordPCB: PCB[0,0,0]

Parameters:
 Required:
  p(0) = posx
  p(1) = posy
  p(2) = capLength for yappRectangle, capDiameter for yappCircle
  p(3) = capWidth for yappRectangle, not used for yappCircle
  p(4) = capAboveLid
  p(5) = switchHeight
  p(6) = switchTravel
  p(7) = poleDiameter
 Optional:
  p(8) = Height to top of PCB : Default = defaultStandoffHeight + pcbThickness
  p(9) = { &lt;yappRectangle&gt;, yappCircle } : buttonType, Default = yappRectangle
  p(10) = filletRadius : Default = 0/Auto 
</pre>

## Rev. 2.0  (21-05-2023)

**New functionality *lightTubes* **

With the **lightTubes** array you can define where you want tubes for LED's and NeoPixles**

<pre>
//-- lightTubes  -- origin is pcb[0,0,0]
// (0) = posx
// (1) = posy
// (2) = tubeLength
// (3) = tubeWidth
// (4) = tubeWall
// (5) = abovePcb
// (6) = tubeType  {yappCircle|yappRectangle}
lightTubes = [
              //--- 0,    1, 2, 3, 4, 5, 6
                  [84.5, 21, 3, 6, 1, 4, yappRectangle]
                , [30,   21, 5, 0, 1, 2, yappCircle]
              ];     
</pre>

lightTube_top
lightTube_a

<pre>
posx        - the position of the center of the led on the X-axes of the PCB
posy        - the position of the center of the led on the Y-axes of the PCB
tubeLength  - the length of the tube (if yappRectangle) or the diameter of the tube (if yappCircle)
tubeWidth   - the width of the tube (not used if yappCircle)
tubeWall    - the width of the wall around the led
abovePcp    - how hight the tube will begin with respect to the top of the PCB
tubeType    - whether the led shows as a circle (yappCircle) or a rectangle (yappRectangle)
</pre>

**New functionality *pushButtons* (experimental)**

With the **pushButtons** array you can define where you want button guides for tactile switches.</br>

<pre>
//-- pushButtons  -- origin is pcb[0,0,0]
// (0) = posx
// (1) = posy
// (2) = capLength
// (3) = capWidth
// (4) = capAboveLid
// (5) = switchHeight
// (6) = switchTrafel
// (7) = poleDiameter
// (8) = buttonType  {yappCircle|yappRectangle}
pushButtons = [
                 [15, 30, 8, 8, 0, 1,   1, 3.5, yappCircle]
               , [15, 10, 8, 6, 2, 4.5, 1, 3.5, yappRectangle]
              ];
</pre>

buttonGuides

The "Plate" has to be glued to the "Pole".

<pre>
posx         - the position of the center of the tacktile switch on the PCB
posy         - the position of the center of the tacktile switch on the PCB
capLength    - the length of the button (if yappRectangle) or the diameter (if yappCircle)
capWidth     - the width of the button (if yappRectangle, otherwise ignored)
capAboveLid  - how much the button cap is above the lid
switchHeight - the height of the tactile switch
switchTrafel - the distance the button has to trafel to activate the tacktile switch
poleDiameter - the diameter of the pole that connects the button cap with the plate
buttonType   - either yappCircle or yappRectangle
</pre>

<hr>

## Rev. 1.8  (22-02-2023)

**This version breaks with the API for the following array's:**

* pcbStand[..] (extra parameter for standoffHeight)
* connectors[..] (extra parameter for baseConnector Height)

<pre>
//-- pcb_standoffs  -- origin is pcb[0,0,0]
// (0) = posx
// (1) = posy
// (2) = standoffHeight
// (3) = flangeHeight
// (4) = flangeDiameter
// (5) = { yappBoth | yappLidOnly | yappBaseOnly }
// (6) = { yappHole, YappPin }
// (7) = { yappAllCorners | yappFrontLeft | yappFrontRight | yappBackLeft | yappBackRight }
pcbStands = [
                [3,  3, 5, 3, 11, yappBoth, yappPin, yappAllCorners]
               ,[5,  5, 5, 4, 10, yappBoth, yappPin, yappBackLeft, yappFrontRight]
               ,[8,  8, 5, 4, 11, yappBoth, yappPin]
               ,[pcbLength-15, pcbWidth-15, 8, 4, 12, yappBoth, yappPin]
             ];
</pre>
<pre>
//-- connectors
//-- normal         : origen = box[0,0,0]
//-- yappConnWithPCB: origen = pcb[0,0,0]
// (0) = posx
// (1) = posy
// (2) = pcbStandHeight
// (3) = screwDiameter
// (4) = screwHeadDiameter
// (5) = insertDiameter
// (6) = outsideDiameter
// (7) = flangeHeight
// (8) = flangeDiam
// (9) = { yappConnWithPCB }
// (10) = { yappAllCorners | yappFrontLeft | yappFrontRight | yappBackLeft | yappBackRight }
connectors   =  [
                    [ 8,  8, 5, 2.5, 2.8, 3.8, 6, 6, 15, yappAllCorners]
                  , [28, 58, 5, 2.5, 2.8, 3.8, 6, 6, 25, yappConnWithPCB]
                ];

</pre>

<hr>

## Rev. 1.7

**This version breaks with the API for the following array's:**

* pcbStand[..] (extra parameter for flange)
* connectors[..] (huge change lots of extra parameters)
* connectosPCB[..] (removed)

<pre>
//-- pcb_standoffs  -- origin is pcb[0,0,0]
// (0) = posx
// (1) = posy
// (2) = flangeHeight
// (3) = flangeDiameter
// (4) = { yappBoth | yappLidOnly | yappBaseOnly }
// (5) = { yappHole, YappPin }
// (6) = { yappAllCorners | yappFrontLeft | yappFrontRight | yappBackLeft | yappBackRight }
pcbStands = [
                [3,  3, 3, 11, yappBoth, yappPin, yappAllCorners]
               ,[5,  5, 4, 10, yappBoth, yappPin, yappBackLeft, yappFrontRight]
               ,[8,  8, 4, 11, yappBoth, yappPin]
               ,[pcbLength-15, pcbWidth-15, 4, 12, yappBoth, yappPin]
             ];
</pre>
<pre>
//-- connectors
//-- normal         : origen = box[0,0,0]
//-- yappConnWithPCB: origen = pcb[0,0,0]
// (0) = posx
// (1) = posy
// (2) = screwDiameter
// (3) = screwHeadDiameter
// (4) = insertDiameter
// (5) = outsideDiameter
// (6) = flangeHeight
// (7) = flangeDiam
// (8) = { yappConnWithPCB }
// (9) = { yappAllCorners | yappFrontLeft | yappFrontRight | yappBackLeft | yappBackRight }
connectors   =  [
                    [8, 8, 2.5, 2.8, 3.8, 6, 6, 15, yappAllCorners]
                  , [28, 58, 2.5, 2.8, 3.8, 6, 6, 25, yappConnWithPCB]
                ];

</pre>

The depth of the screw in the connectors is now depending on the standoffHeight so the
screw size does not change anymore.
YAPP_connectorRevised

<hr>

## Rev. 1.6

- new cutoutGrills array
<pre>
//-- cutoutGrills    -- origin is box[x0,y0]
// (0) = xPos
// (1) = yPos
// (2) = grillWidth
// (3) = grillLength
// (4) = gWidth
// (5) = gSpace
// (6) = gAngle
// (7) = plane [ "base" | "lid" ]
// (8) = {polygon points} (optional)

cutoutGrills = [
                 [22, 22, 90, 90, 2, 3, 50, "base", [  [0,15],[20,15],[30,0],[40,15],[60,15]
                                                      ,[50,30],[60,45], [40,45],[30,60]
                                                      ,[20,45], [0,45],[10,30] ]
                 ]
                ,[15, 10, 50, 10, 2, 3, -20, "base"]
                ,[15, 15, 10, 50, 2, 3, -45, "lid"]
                ,[15, 85, 50, 10, 2, 3,  20, "base"]
                ,[85, 15, 10, 50, 2, 3,  45, "lid"]
               ];
</pre>
cutoutGrills-v16

**Be aware**: this functionality needs a **huge** amount of rendering elements.

You can set this at `Preferences->Advanced->Turn of rendering at 100000 elements`
<hr>

## Rev. 1.5

- Various bug-fixes
- Connectors now have a flange at the basePlane and lidPlane for a better adhesion

*This release breaks with previous releases in the extra parm "**depth**" in the labels array!!*

The labels now have this syntax:
<pre>
//-- origin of labels is box [0,0,0]
// (0) = posx
// (1) = posy/z
// (2) = orientation
// (3) = depth
// (4) = plane {lid | base | left | right | front | back }
// (5) = font
// (6) = size
// (7) = "label text"
</pre>

Example:
<pre>
labelsPlane = [
                [10,  10,   0, 0.6, "lid",   "Liberation Mono:style=bold", 15, "YAPP" ]
               ,[100, 90, 180, 0.8, "base",  "Liberation Mono:style=bold", 11, "Base" ]
               ,[8,    8,   0, 1.0, "left",  "Liberation Mono:style=bold",  7, "Left" ]
               ,[10,   5,   0, 1.2, "right", "Liberation Mono:style=bold",  7, "Right" ]
               ,[40,  23,   0, 1.5, "front", "Liberation Mono:style=bold",  7, "Front" ]
               ,[5,    5,   0, 2.0, "back",  "Liberation Mono:style=bold",  8, "Back" ]
              ];
</pre>

For your box to work with this release as before you have to add this extra 
parm (as "wallThickness/2", "basePlaneThickness/2" or "lidPlaneThickness/2").

Thanks to *Keith Hadley*

There now is a new array for connectors that holds the PCB. This array is called "**connectorsPCB**".
<pre>
//-- connectorsPCB -- origin = pcb[0,0,0]
// (0) = posx
// (1) = posy
// (2) = screwDiameter
// (3) = insertDiameter
// (4) = outsideDiameter
// (5) = { yappAllCorners }
</pre>

Example:
<pre>
connectorsPCB = [
                  [pcbLength/2, 10, 2.5, 3.8, 5]
                 ,[pcbLength/2, pcbWidth-10, 2.5, 3.8, 5]
                ];
</pre>
It takes in account the "**pcbThickness**" to calculate the hight of the lid-connector.

Thanks to *Oliver Grafe*

connectorTypes

<hr>

## Rev. 1.4

*This release breaks with previous releases in the extra parm "**angle**" in all the cutouts array's!!!*

All plane array's now have this syntax:

<pre>
//-- plane    -- origin is pcb[0,0,0]
// (0) = posx
// (1) = posy
// (2) = width
// (3) = length
// (4) = angle
// (5) = { yappRectangle | yappCircle }
// (6) = { yappCenter }
</pre>

For your box to work with this release you have to add this extra parm (as "***0***") to all your cutOut-array-row's

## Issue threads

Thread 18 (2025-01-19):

zijn er plannen on watermeter ook uit te lezen?

PeterSchops, 2025-01-19:
In Belgie krijgen nieuwe installaties ook een watermeter, dus het leek me interessant om die ook mee te loggen.
Het zou gelijkaardig kunnen zijn als het gasverbruik.

mrWheel, 2025-01-20:
Als de water meter wordt aangesloten op de mBus van de Slimme Meter dan kun je dat gewoon in de GUI configureren.

PeterSchops, 2025-01-20:
De data wordt inderdaad reeds uitgelezen. Met als eenheid is GJ ipv m3.
Ik bedoelde echter of er plannen waren om die in het grafische overzicht op te nemen, om zo ook het waterverbruik op te volgen, per dag en per maand. Voor de moment gebruik ik de vorige versie met ESP8266, maar heb nieuwe hardware besteld om de nieuwe versie ook eens te proberen.

Name | Value | Unit
-- | -- | --
MBus-1 Gebruikt | 0.009 | m3
MBus-2 Gebruikt | 0.36 | GJ
MBus-3 Gebruikt | 0 | m3
MBus-4 Gebruikt | 0 | m3
Gas Gebruikt | 0.014 | m3

Als er geen plannen zijn, ga ik proberen om het zelf toe te voegen. Als ik het in kleine stappen doe, lijkt het iets wat doenbaar is. Eerst water waarden toevoegen in de ring-files, en hopelijk breekt dat het web gedeelte niet. En dan in een 2e stap de web pagina updaten.

mrWheel, 2025-01-21:
@PeterSchops,

Nee, ik heb voorlopig geen plannen om aanpassingen aan de firmware te doen.

Closed 2025-01-20.

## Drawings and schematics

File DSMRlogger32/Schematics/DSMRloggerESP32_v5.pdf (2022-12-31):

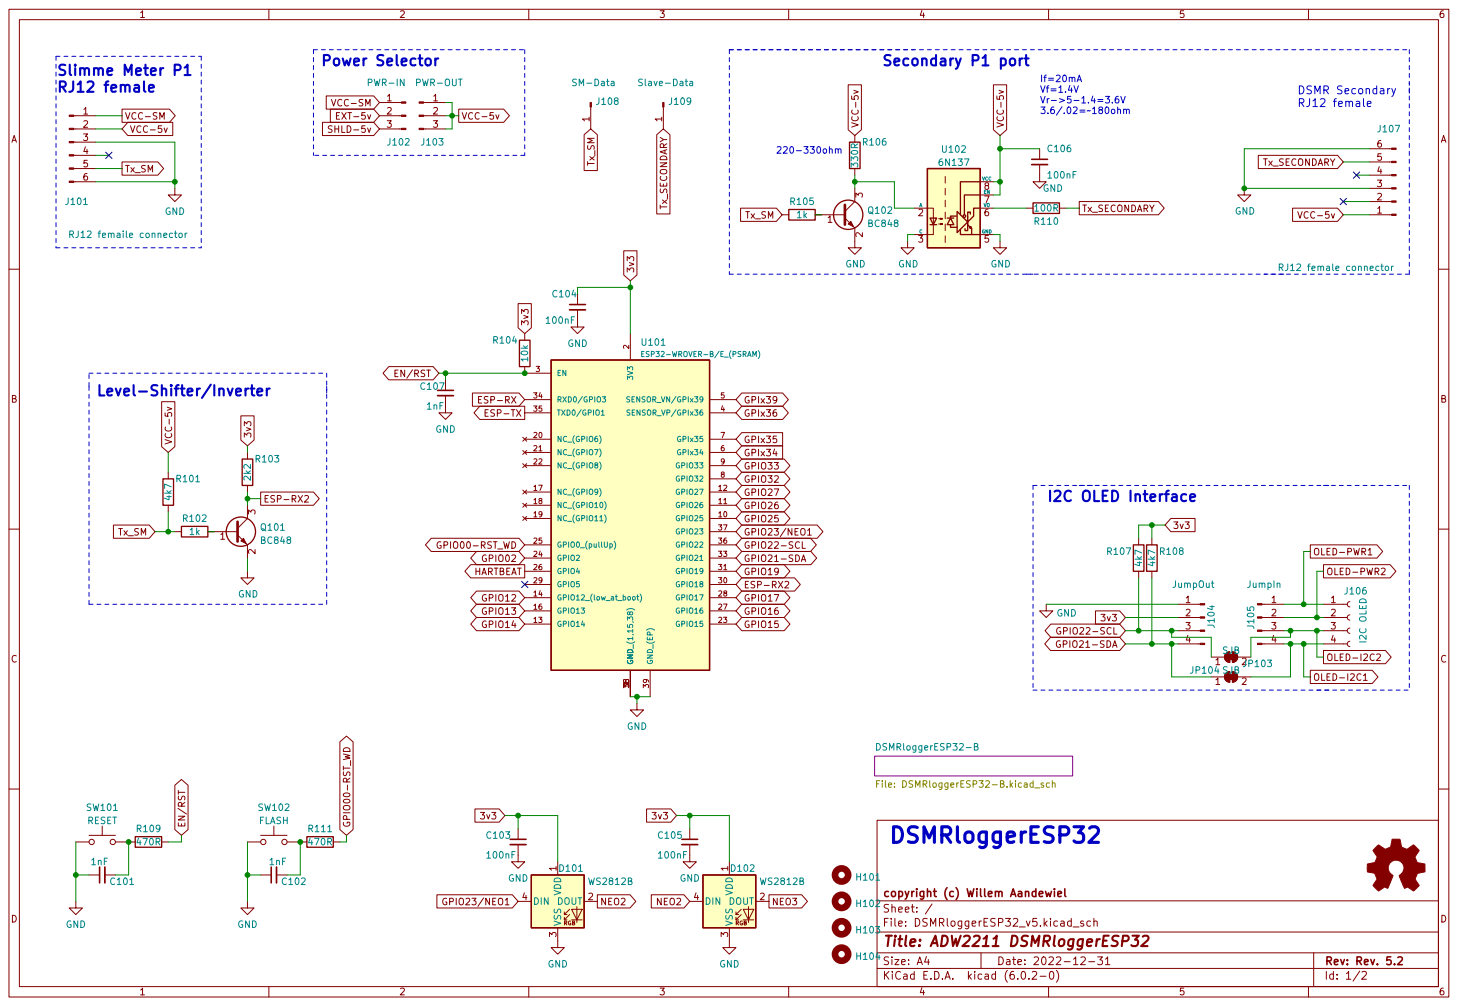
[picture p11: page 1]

2 NC_(GPIO6) 20 NC_(GPIO7) 21 NC_(GPIO8) 22 GPIO15 23 GPIO2 24 GPIO0_(pullUp) 25 GPIO4 26 GPIO16 27 GPIO17 28 GPIO5 29 EN 3 GPIO18 30 GPIO19 31 GPIO21 33 RXD0/GPIO3 34 TXD0/GPIO1 35 GPIO22 36 GPIO23 37 GND 38 GND_(EP) 39 SENSOR_VP/GPIx36 4 SENSOR_VN/GPIx39 5 GPIx34 6 GPIx35 7 GPIO32 8 GPIO33 9 U101

File: DSMRloggerESP32_v5.kicad_sch Sheet: / copyright (c) Willem Aandewiel

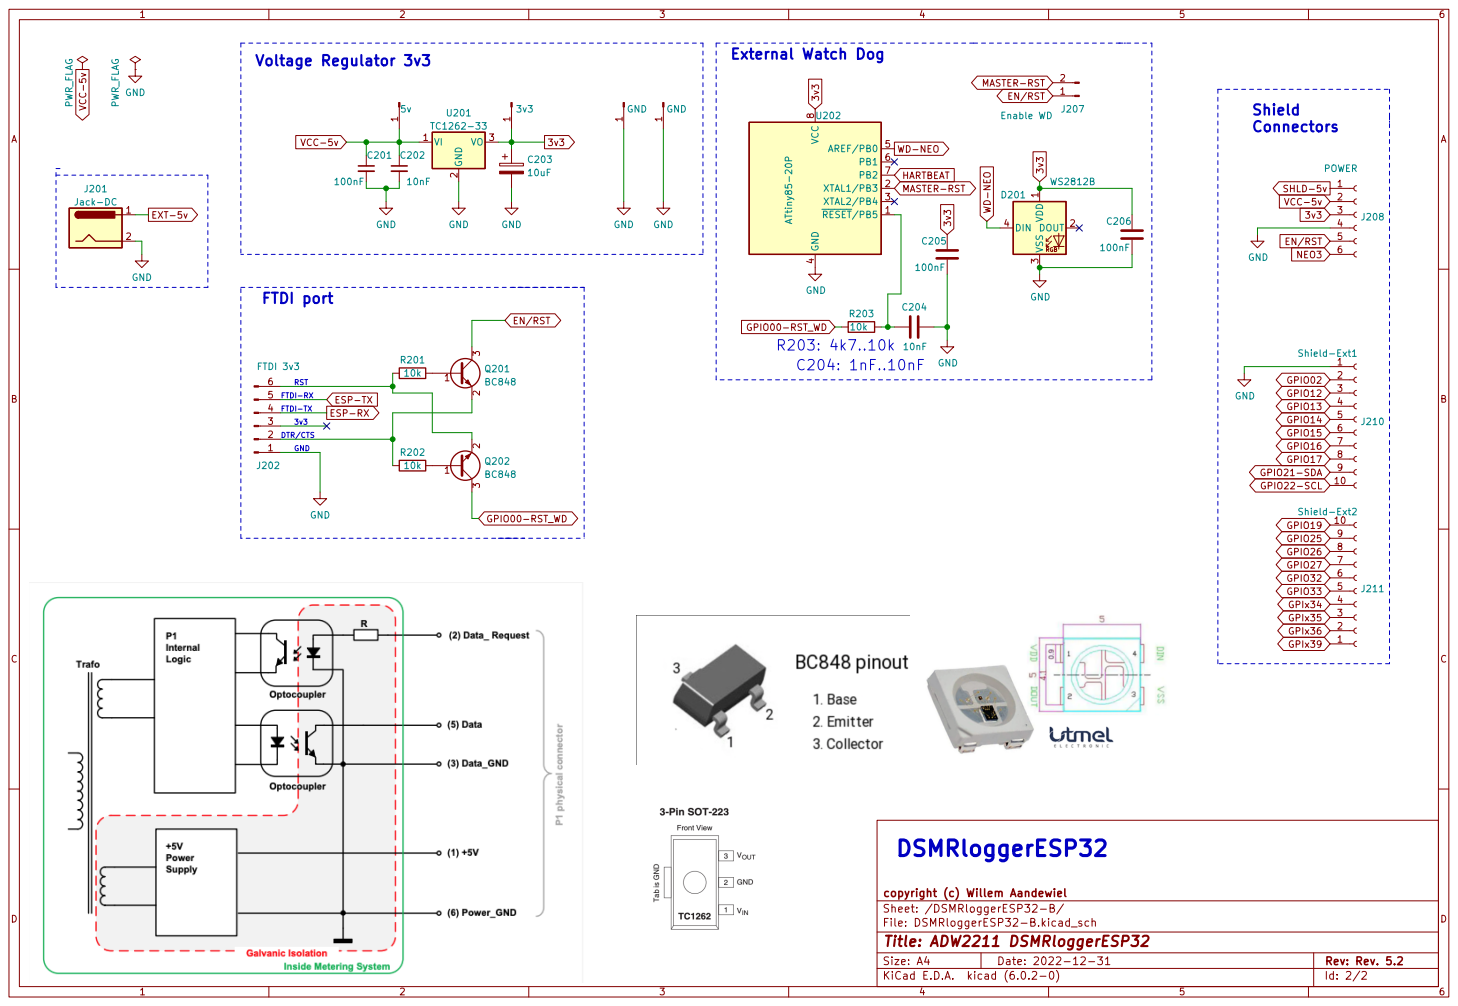
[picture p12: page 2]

FTDI-RX DTR/CTS FTDI port GND Voltage Regulator 3v3
Jack-DC PWR_FLAG GND

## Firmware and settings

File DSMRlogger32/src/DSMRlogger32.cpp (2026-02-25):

/*
***************************************************************************
**  Program  : DSMRlogger32 (restAPI)
*/
const char* PROG_VERSION = "v5.4.3 (25-02-2026)";
/*
**  Copyright (c) 2022, 2023, 2024 Willem Aandewiel
**
**  TERMS OF USE: MIT License. See bottom of file.
***************************************************************************
**
**  platformio.ini for DSMR-logger32 Revision 5 (ESP32): 
**
**    [platformio]
**    workspace_dir = .pio.nosync
**    default_envs = DSMRlogger32
**
**    [env:DSMRlogger32]
**    platform = espressif32
**    board = esp32dev
**    framework = arduino
**    ;board_build.partitions = min_spiffs.csv
**    ;board_build.partitions = huge_app.csv
**    board_build.partitions = ./partitions32.csv
**    board_build.filesystem = spiffs
**    board_build.flash_mode = qio
**    board_build.f_flash = 80000000
**    monitor_speed = 115200
**    upload_speed = 230400
**    ;-- change next line to your system
**    upload_port = /dev/cu.usbserial-3224142
**    build_flags = -w
**    ;      CORE_DEBUG_LEVEL: (0)NoLogging, (1)Error, (2)Warning, (3)Info, (4)Debug, (5)Verbose
**        -D CORE_DEBUG_LEVEL=3
**    	  -D BOARD_HAS_PSRAM
**    lib_ldf_mode = deep+
**    lib_deps =
**    	https://github.com/mrWheel/SPIFFS_SysLogger
**    	https://github.com/mrWheel/dsmr2Lib
**      https://github.com/mrWheel/TimeSyncLib
**    	greiman/SSD1306Ascii@^1.3.5
**    	jandrassy/TelnetStream@^1.3.0
**    	tzapu/WiFiManager@^2.0.17
**    	adafruit/Adafruit NeoPixel@^1.12.3
**      bblanchon/ArduinoJson@6.21.5
**    	knolleary/PubSubClient@^2.8
**    monitor_filters =
**    	esp32_exception_decoder

**
**  partition32.csv
**    # Name,   Type, SubType, Offset,  Size, Flags
**    nvs,      data, nvs,     0x9000,  0x5000,
**    otadata,  data, ota,     0xe000,  0x2000,
**    app0,     app,  ota_0,   0x10000, 0x180000,
**    app1,     app,  ota_1,   0x190000,0x180000,
**    spiffs,   data, spiffs,  0x310000,0x80000,
**
**  Coding Style  ( http://astyle.sourceforge.net/astyle.html#_Quick_Start )
**   - Allman style (-A1)
**   - tab 2 spaces (-s2)
**   - Indent 'switch' blocks (-S)
**   - Indent preprocessor blocks (-xW)
**   - Indent multi-line preprocessor definitions ending with a backslash (-w)
**   - Indent C++ comments beginning in column one (-Y)
**   - Insert space padding after commas (-xg)
**   - Attach a pointer or reference operator (-k3)
**
**  use:  astyle -A1 -s2 -S -xW -w -Y -xg- k3 *.{ino|h}
**
**  remove <filename>.orig afterwards
**
*/

/*
**  You can find more info in the following links (all in Dutch):
**   https://willem.aandewiel.nl/index.php/2020/02/28/restapis-zijn-hip-nieuwe-firmware-voor-de-dsmr-logger/
**   https://mrwheel-docs.gitbook.io/DSMRloggerAPI/
**   https://mrwheel.github.io/DSMRloggerWS/
**
**   https://mrwheel-docs.gitbook.io/DSMRlogger32/
*/

/******************** don't change anything below this comment **********************/

#include "DSMRlogger32.h"

//=======================================================================
float typecastValue(TimestampedFixedValue i)
{
  return strToFloat(String(i).c_str(), 3);
}

//=======================================================================
float typecastValue(FixedValue i)
{
  return i;
}

TimeSync timeSync; //-- new, not in Arduino version
struct tm timeinfo;
time_t now;

//===========================================================================================
void displayStatus()
{
  if (devSetting->OledType > 0)
  {
    switch (msgMode)
    {
    case 1:
    {
      memset(fChar, 0, _FCHAR_LEN);
      //----- PROG_VERSION format "vx.y.z (dd-mm-eeyy)"
      //-----                      012345  8901234567
      snprintf(fChar, _FCHAR_LEN, "%s", PROG_VERSION);
      int d = 0, s = 0;
      for (s = 0; s < 6; s++)
      {
        gMsg[d++] = fChar[s];
      }
      gMsg[d++] = ' ';
      gMsg[d++] = ' ';
      for (s = 8; s < 18; s++)
      {
        gMsg[d++] = fChar[s];
      }
      gMsg[d++] = 0;
      snprintf(gMsg, _GMSG_LEN, "%s", gMsg);
    }
    break;
    case 2:
      snprintf(gMsg, _GMSG_LEN, "Up:%-15.15s", upTime().c_str());
      break;
    case 3:
      if (runAPmode)
        snprintf(gMsg, _GMSG_LEN, "** ACCESS POINT **");
      else
        snprintf(gMsg, _GMSG_LEN, "WiFi RSSI:%4d dBm", WiFi.RSSI());
      break;
    case 4:
      if (runAPmode)
        snprintf(gMsg, _GMSG_LEN, "SSID: %s", devSetting->Hostname);
      else
      {
        if (WiFi.status() != WL_CONNECTED)
          snprintf(gMsg, _GMSG_LEN, "**** NO  WIFI ****");
        else
          snprintf(gMsg, _GMSG_LEN, "IP %s", WiFi.localIP().toString().c_str());
      }
      break;
    default:
      snprintf(gMsg, _GMSG_LEN, "Telgrms:%6d/%3d", telegramCount, telegramErrors);
      break;
    }

    oled_Print_Msg(3, gMsg, 0);
    //-- modular 5 = number of message displayed (hence it cycles thru the messages
    msgMode = (msgMode + 1) % 5;
  }
} // displayStatus()

//===========================================================================================
void setup()
{
  Serial.begin(115200);
  while (!Serial)
  {
    delay(10);
  }

  upTimeStart = millis() / 1000;

  neoPixels.begin();
  neoPixels.show();
  neoPixels.setBrightness(125);

  DebugTln("blink Neo Pixels ..");
  blinkNeoPixels(5, 750);
  neoPixOn(0, neoPixRed);
  neoPixOn(1, neoPixRed);

  // for now 115200. Look at end of setup()
  SMserial.begin(115200, SERIAL_8N1, SMRX, SMTX);

  Debugln("\n\n*******************************************************");
  Debugf("* Booting....[%s] \r\n", String(PROG_VERSION).c_str());
  Debugln("*******************************************************\r\n");
  DebugFlush();

  heap_caps_malloc_extmem_enable(_PSRAM_LIMIT);

  //-- claim PSRAM
  setupPsram();

  pinMode(LED_BUILTIN, OUTPUT);
  pinMode(_DTR_ENABLE, OUTPUT);
  pinMode(_FLASH_BUTTON, INPUT_PULLUP);
  pinMode(_PIN_HEARTBEAT, OUTPUT);
  pinMode(_PIN_WD_RESET, OUTPUT);

  //-- Hold WatchDog
  DebugTln("Reset Watchdog ..");
  resetWatchdog();

  pulseHeart(true);
  neoPixOn(0, neoPixRed);
  neoPixOff(1);

  runAPmode = !digitalRead(_FLASH_BUTTON);
  if (runAPmode)
    DebugTln("run in AP mode requested by user!");

  //------ initialize File System --------------------------
  setupFileSystem();

  //------ initialize devSetting logger --------------------
  setupSysLogger(PROG_VERSION);

  readDevSettings(true);
  readShieldSettings(true);

  if (devSetting->runAPmode > 0)
  {
    runAPmode = true;
    DebugTln("device setting: run as AP!");
  }
  oled_Init();

  //=============start Networkstuff==================================
  Serial.println(">>DSMR-logger32<<");
  Serial.println("Verbinden met WiFi...");

  if (devSetting->OledType > 0)
  {
    if (devSetting->OledFlip)
      oled_Init(); // only if true restart(init) oled screen
    oled_Clear();  // clear the screen
    oled_Print_Msg(0, ">>DSMR-logger32<<", 0);
    oled_Print_Msg(1, "Verbinden met WiFi", 500);
  }
  digitalWrite(LED_BUILTIN, LED_ON);
  if (!runAPmode)
  {
    startWiFi(devSetting->Hostname, 240, false); // timeout 4 minuten
    myWiFi.ipWiFi = WiFi.localIP();
    myWiFi.ipGateway = WiFi.gatewayIP();
    DebugT("DSMRlogger32 IP address: ");
    Debugln(WiFi.localIP());

    WiFi.onEvent(WiFiEvent);
  }
  else
  {
    if (devSetting->runAPmode)
      writeToSysLog("run in AP mode by system setting!");
    else
      writeToSysLog("run in AP mode requested by user!");
    WiFi.softAP(devSetting->Hostname);
    DebugT("AP IP address: ");
    Debugln(WiFi.softAPIP());
    lostWiFiConnection = false;
  }
  //--- setup randomseed the right way (??)
  //--- Read more: http://www.esp32learning.com/code/esp32-true-random-number-generator-example.php
  esp_random();

  if (devSetting->OledType > 0)
  {
    oled_Print_Msg(0, ">>DSMR-logger32<<", 0);
    if (runAPmode)
      oled_Print_Msg(1, devSetting->Hostname, 0);
    else
      oled_Print_Msg(1, WiFi.SSID(), 0);
    if (runAPmode)
      snprintf(gMsg, _GMSG_LEN, "IP %s", WiFi.softAPIP().toString().c_str());
    else
      snprintf(gMsg, _GMSG_LEN, "IP %s", WiFi.localIP().toString().c_str());
    oled_Print_Msg(2, gMsg, 1500);
  }

  startTelnet();
  if (devSetting->OledType > 0)
  {
    oled_Print_Msg(0, ">>DSMR-logger32<<", 0);
    oled_Print_Msg(3, "telnet (poort 23)", 2500);
  }

  digitalWrite(LED_BUILTIN, LED_OFF);

  Debugln();
  DebugT("Connected to ");
  if (runAPmode)
    Debugln(devSetting->Hostname);
  else
    Debugln(myWiFi.SSID);
  DebugT("IP address: ");
  if (runAPmode)
    Debugln(WiFi.softAPIP());
  else
    Debugln(myWiFi.ipWiFi);
  if (!runAPmode)
  {
    DebugT("IP gateway: ");
    Debugln(myWiFi.ipGateway);
  }
  Debugln();

  for (int L = 0; L < 4; L++)
  {
    digitalWrite(LED_BUILTIN, !digitalRead(LED_BUILTIN));
    delay(200);
  }
  digitalWrite(LED_BUILTIN, LED_OFF);

  startMDNS(devSetting->Hostname);
  if (devSetting->OledType > 0)
  {
    oled_Print_Msg(3, "mDNS gestart", 1500);
  }

  //=============end Networkstuff======================================

  //------ read status file for last Timestamp --------------------
  strlcpy(lastTlgrmTime.Timestamp, "040302010101X", _TIMESTAMP_LEN);
  //==========================================================//
  // writeLastStatus();  // only for firsttime initialization //
  //==========================================================//
  readLastStatus(); // place it in lastTlgrmTime.Timestamp

  DebugTf("last used time [%s]\r\n", lastTlgrmTime.Timestamp);

  //-- make sure both prev and last are initialized
  saveTimestamp(lastTlgrmTime.Timestamp);
  saveTimestamp(lastTlgrmTime.Timestamp);

  timeSync.setup();
  timeSync.sync(100);
  time(&now);
  DebugTf("===> lastTimestamp[%s]-> nrReboots[%u] - Errors[%u]\r\n\n", lastTlgrmTime.Timestamp, nrReboots++, slotErrors);

  readSmSettings(true);

  if (devSetting->OledType > 0)
  {
    oled_Init();
    oled_Clear(); // clear the screen so we can paint the menu.
    oled_Print_Msg(0, ">>DSMR-logger32<<", 0);
    int8_t sPos = String(PROG_VERSION).indexOf(' ');
    snprintf(gMsg, _GMSG_LEN, "(c)2022..2024 [%s]", String(PROG_VERSION).substring(0, sPos).c_str());
    oled_Print_Msg(1, gMsg, 0);
    oled_Print_Msg(2, " Willem Aandewiel", 0);
    oled_Print_Msg(3, " >> Have fun!! <<", 1000);
    yield();
  }
  else // don't blink if oled-screen attatched
  {
    for (int I = 0; I < 2; I++)
    {
      digitalWrite(LED_BUILTIN, !digitalRead(LED_BUILTIN));
      delay(250);
    }
  }
  digitalWrite(LED_BUILTIN, LED_OFF); // HIGH is OFF

  if (filesysMounted)
  {
    if (devSetting->OledType > 0)
    {
      oled_Print_Msg(0, ">>DSMR-logger32<<", 0);
      oled_Print_Msg(3, "Filesystm mounted", 1500);
    }
  }
  else
  {
    if (devSetting->OledType > 0)
    {
      oled_Print_Msg(0, ">>DSMR-logger32<<", 0);
      oled_Print_Msg(3, "MOUNT FS FAILED!", 2000);
    }
  }

  while (!psramFound())
  {
    DebugTln("*******************************************");
    DebugTln("**   This module does not have PSRAM!!   **");
    DebugTln("** Firmware will not run on this module! **");
    DebugTln("*******************************************\r\n");
    //-- send heartbeat for 2 minutes
    uint32_t waitTimer = millis();
    while ((millis() - waitTimer) < 120000)
    {
      pulseHeart();
      delay(10000);
    }
    DebugTln("No more heartbeats from now!\r\n");
    //-- now wait for Watchdog to reset this module
    while (1)
    {
      delay(1000);
    }
  }

  /**
    if (strlen(devSetting->Hostname) == 0)
    {
      snprintf(devSetting->Hostname, sizeof(devSetting->Hostname), "%s", _DEFAULT_HOSTNAME);
    }
  **/
  writeToSysLog("Hostname [%s]", devSetting->Hostname);
  //-- Press [Reset] -> "External System"
  //-- Software reset -> "Vbat power on reset"
  getLastResetReason(rtc_get_reset_reason(0), lastResetCPU0, 99);
  DebugTf("last Reset Reason CPU[0] - %s\r\n", lastResetCPU0);
  writeToSysLog("last Reset Reason CPU[0] - %s", lastResetCPU0);
  getLastResetReason(rtc_get_reset_reason(1), lastResetCPU1, 99);
  DebugTf("last Reset Reason CPU[1] - %s\r\n", lastResetCPU1);
  writeToSysLog("last Reset Reason CPU[1] - %s", lastResetCPU1);

  if (!runAPmode)
  {
    //================ startNTP =========================================
    if (devSetting->OledType > 0)
    {
      oled_Print_Msg(3, "setup NTP server", 100);
    }
    time(&now);
    DebugTln(F("NTP server set!\r\n\r"));
    DebugTf("NTP Date/Time: %02d-%02d-%04d %02d:%02d:%02d\r\n", localtime(&now)->tm_mday, localtime(&now)->tm_mon + 1, localtime(&now)->tm_year + 1900, localtime(&now)->tm_hour, localtime(&now)->tm_min, localtime(&now)->tm_sec);
    writeToSysLog("NTP Date/Time: %02d-%02d-%04d %02d:%02d:%02d", localtime(&now)->tm_mday, localtime(&now)->tm_mon + 1, localtime(&now)->tm_year + 1900, localtime(&now)->tm_hour, localtime(&now)->tm_min, localtime(&now)->tm_sec);

    if (devSetting->OledType > 0)
    {
      oled_Print_Msg(0, ">>DSMR-logger32<<", 0);
      oled_Print_Msg(3, "NTP gestart", 1500);
    }

    // if (timeSet) { ntpEventId = setEvent(logNtpTime, now()+3600); }

  } //-- !runAPmode

  //-- OK, WiFi connected, time set
  neoPixOn(0, neoPixGreen);

  //================ end NTP =========================================

  // writeToSysLog(lastReset);

  Serial.print("\nGebruik 'telnet ");
  if (runAPmode)
    Serial.print(WiFi.softAPIP());
  else
    Serial.print(WiFi.localIP());
  Serial.println("' voor verdere debugging\r\n");

  //=============now test if FS is correct populated!============
  filesysNotPopulated = setupIsFsPopulated();

  if (devSetting->OledType > 0)
  {
    snprintf(gMsg, _GMSG_LEN, "DT: %02d%02d%02d%02d0101x", thisYear, thisMonth, thisDay, thisHour);
    oled_Print_Msg(0, ">>DSMR-logger32<<", 0);
    oled_Print_Msg(3, gMsg, 1500);
  }

  //================ Start MQTT  ======================================

  connectMQTT();
  if (devSetting->OledType > 0)
  {
    oled_Print_Msg(0, ">>DSMR-logger32<<", 0);
    oled_Print_Msg(3, "MQTT server set!", 1500);
  }

  //================ Start HTTP Server ================================

  if (!filesysNotPopulated)
  {
    DebugTln(F("Filesystem correct populated -> normal operation!\r"));
    if (devSetting->OledType > 0)
    {
      oled_Print_Msg(0, ">>DSMR-logger32<<", 0);
      oled_Print_Msg(1, "OK, FS correct", 0);
      oled_Print_Msg(2, "Verder met normale", 0);
      oled_Print_Msg(3, "Verwerking ;-)", 2500);
    }
    if (hasAlternativeIndex)
    {
      httpServer.serveStatic("/", _FSYS, devSetting->IndexPage);
      httpServer.serveStatic("/index", _FSYS, devSetting->IndexPage);
      httpServer.serveStatic("/index.html", _FSYS, devSetting->IndexPage);
      httpServer.serveStatic("/DSMRindex.html", _FSYS, devSetting->IndexPage);
    }
    else
    {
      httpServer.serveStatic("/", _FSYS, "/DSMRindex.html");
      httpServer.serveStatic("/DSMRindex.html", _FSYS, "/DSMRindex.html");
      httpServer.serveStatic("/index", _FSYS, "/DSMRindex.html");
      httpServer.serveStatic("/index.html", _FSYS, "/DSMRindex.html");
      httpServer.serveStatic("/DSMRindex.css", _FSYS, "/DSMRindex.css");
      httpServer.serveStatic("/DSMRindex.js", _FSYS, "/DSMRindex.js");
      httpServer.serveStatic("/DSMRgraphics.js", _FSYS, "/DSMRgraphics.js");
    }
  }
  else
  {
    DebugTln(F("Oeps! not all files found on FS -> Start FSmanager!\r"));
    filesysNotPopulated = true;
    if (devSetting->OledType > 0)
    {
      oled_Print_Msg(0, "!OEPS! niet alle", 0);
      oled_Print_Msg(1, "files op FS", 0);
      oled_Print_Msg(2, "gevonden! (fout!)", 0);
      oled_Print_Msg(3, "Start FSmanager", 2000);
    }
    neoPixOn(1, neoPixRed);
  }

  setupFSmanager();

  httpServer.on("/api", HTTP_GET, processAPI);
  // all other api calls are catched in FSmanager onNotFounD!

  httpServer.begin();
  DebugTln("HTTP server gestart\r");
  if (devSetting->OledType > 0) // HAS_OLED
  {
    // HAS_OLED
    oled_Clear();                               // HAS_OLED
    oled_Print_Msg(0, ">>DSMR-logger32<<", 0);  // HAS_OLED
    oled_Print_Msg(2, "HTTP server ..", 0);     // HAS_OLED
    oled_Print_Msg(3, "gestart (poort 80)", 0); // HAS_OLED
  }

  httpUpdater.setup(&httpServer);

  //================ Start HTTP Server ================================

  DebugTf("Startup complete! lastTlgrmTime[%s]\r\n", lastTlgrmTime.Timestamp);
  writeToSysLog("Startup complete! lastTlgrmTime[%s]", lastTlgrmTime.Timestamp);

  if (devSetting->OledType > 0)
  {
    oled_Print_Msg(0, ">>DSMR-logger32<<", 0);
    oled_Print_Msg(1, "Startup complete", 0);
    oled_Print_Msg(2, "Wait for first", 0);
    oled_Print_Msg(3, "telegram .....", 500);
  }

  //================ Start Shield =====================================
  relay0.setup(shieldSetting[0]->GPIOpin, shieldSetting[0]->inversed, shieldSetting[0]->activeStart, shieldSetting[0]->activeStop, shieldSetting[0]->onThreshold, shieldSetting[0]->offThreshold, shieldSetting[0]->onDelay, shieldSetting[0]->offDelay);
  relay1.setup(shieldSetting[1]->GPIOpin, shieldSetting[1]->inversed, shieldSetting[1]->activeStart, shieldSetting[1]->activeStop, shieldSetting[1]->onThreshold, shieldSetting[1]->offThreshold, shieldSetting[1]->onDelay, shieldSetting[1]->offDelay);

  //================ Start Slimme Meter ===============================

  DebugTln(F("Enable slimmeMeter..\r"));

  DebugTln("Setup serial port for Smart Meter reading");
  if (smSetting->PreDSMR40 == 0)
  {
    DebugTf("SMserial is set to 115200 baud / 8N1 (RX=%d, TX=%d)\r\n", SMRX, SMTX);
    DebugFlush();
    SMserial.end();
    delay(100);
    SMserial.begin(115200, SERIAL_8N1, SMRX, SMTX);
    slimmeMeter.doChecksum(true);
  }
  else
  {
    // PRE40
    DebugTf("SMserial is set to 9600 baud / 7E1 (RX=%d, TX=%d)\r\n", SMRX, SMTX);
    DebugFlush();
    SMserial.end();
    delay(100);
    SMserial.begin(9600, SERIAL_7E1, SMRX, SMTX);
    slimmeMeter.doChecksum(false);
  }

  neoPixOn(1, neoPixGreenLow);

  updatedRINGfiles = false;

  delay(100);
  slimmeMeter.enable(true);

  DebugTln("reached end of setup()!");

} // setup()

//===[ no-blocking delay with running background tasks in ms ]============================
DECLARE_TIMER_MS(timer_delay_ms, 1);
void delayms(unsigned long delay_ms)
{
  CHANGE_INTERVAL_MS(timer_delay_ms, delay_ms);
  RESTART_TIMER(timer_delay_ms);
  while (!DUE(timer_delay_ms))
  {
    doSystemTasks();
  }

} // delayms()
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
void loop()
{
  //--- do the tasks that has to be done
  //--- as often as possible
  doSystemTasks();
  doTaskTelegram();
  doTaskShield();

  loopCount++;

  //--- if an OLED screen attached, display the status
  if (devSetting->OledType > 0)
  {
    if (DUE(updateDisplay))
    {
      displayStatus();
    }
  }

  //--- if connection lost, try to reconnect to WiFi
  if (lostWiFiConnection)
  {
    neoPixOn(0, neoPixRed);
    if (firstConnectionLost)
    {
      // writeToSysLog("Watchdog timer reset ...");
      firstConnectionLost = false;
      resetWatchdog();
    }

    glowTimer0 = millis() + 2000;
    if ((lostWiFiCount % 25) == 0)
    {
      DebugTf("Reconnect wifi with [%s]...\r\n", devSetting->Hostname);
      writeToSysLog("Reconnect wifi with [%s]...", devSetting->Hostname);
    }
    WiFi.disconnect();
    // WiFi.reconnect();
    delay(1000);
    WiFi.begin(myWiFi.SSID, myWiFi.password);
    delay(1000);
    if (WiFi.status() != WL_CONNECTED)
    {
      if (lostWiFiConnection && (lostWiFiCount % 25) == 0)
      {
        DebugTln("Wifi still not connected!");
        writeToSysLog("Wifi still not connected!");
      }
    }
    else
    {
      snprintf(gMsg, _GMSG_LEN, "IP:[%s], Gateway:[%s]", WiFi.localIP().toString().c_str(), WiFi.gatewayIP().toString().c_str());
      DebugTf("%s\r\n", gMsg);
      writeToSysLog("%s", gMsg);
      startMDNS(devSetting->Hostname);
    }
  } //  lostWiFiConnection
  else
  {
    //-- set NEO 0 to Green
    if ((millis() - glowTimer0) > _GLOW_TIME)
    {
      neoPixOn(0, neoPixGreenLow);
    }
  }

  yield();

} // loop()

/***************************************************************************
 *
 * Permission is hereby granted, free of charge, to any person obtaining a
 * copy of this software and associated documentation files (the
 * "Software"), to deal in the Software without restriction, including
 * without limitation the rights to use, copy, modify, merge, publish,
 * distribute, sublicense, and/or sell copies of the Software, and to permit
 * persons to whom the Software is furnished to do so, subject to the
 * following conditions:
 *
 * The above copyright notice and this permission notice shall be included
 * in all copies or substantial portions of the Software.
 *
 * THE SOFTWARE IS PROVIDED "AS IS", WITHOUT WARRANTY OF ANY KIND, EXPRESS
 * OR IMPLIED, INCLUDING BUT NOT LIMITED TO THE WARRANTIES OF
 * MERCHANTABILITY, FITNESS FOR A PARTICULAR PURPOSE AND NONINFRINGEMENT.
 * IN NO EVENT SHALL THE AUTHORS OR COPYRIGHT HOLDERS BE LIABLE FOR ANY
 * CLAIM, DAMAGES OR OTHER LIABILITY, WHETHER IN AN ACTION OF CONTRACT, TORT
 * OR OTHERWISE, ARISING FROM, OUT OF OR IN CONNECTION WITH THE SOFTWARE OR
 * THE USE OR OTHER DEALINGS IN THE SOFTWARE.
 *
 ***************************************************************************/

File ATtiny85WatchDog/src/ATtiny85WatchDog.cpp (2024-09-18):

/*
** ATtiny85 Watch Dog for an ESP8266/ESP32 or any other MCU
** 
** Copyright 2022 .. 2024 Willem Aandewiel
** Version 3.1  (18-09-2024)
** 
** Use [PROJECT TASKS] to set fuses (as in 'platformio.ini'):
**   - High Fuse: Serial program downloading (SPI) enabled
**   - High Fuse: Brown-out detector triggel level: Brown-out detection at VCC=1.8 V
**   - Low Fuse:  Select Clock Source: Int. RC Osc. 8 MHz; Start-up time PWRDWN/RESET: 6 CK/14 CK + 64 ms
**  
**      Low       : 0xE2
**      High      : 0xDE (but 0xDF might also "work" --> brown-out detection disabled)
**      Extended  : 0xFF
**
** ATMEL ATTINY85
**                        +--\/--+
**             RESET PB5 1|      |8 VCC
**    <--[ESP32_EN]  PB3 2|      |7 PB2  (INT0) <----- heartbeat
**       [RESET_ME]  PB4 3|      |6 PB1  [x] 
**                   GND 4|      |5 PB0  [NEO_LED] -> 
**                        +------+
**
**  Boot sequence:
**  ==============
**  State        | NEOPIXEL                | Remark
**  -------------+-------------------------+--------------------------------------
**  Power On     | BLUE                    | Fade On ~6 sec, fade Off 6 sec 
**               |                         | (duration: _STARTUP_TIME seconds) 
**               |                         | Next: "Normal Operation"
**  -------------+-------------------------+--------------------------------------
**  Normal       | GREEN HeartBeat         | Fade On ~5 sec, fade Off ~5 sec
**  Operation    |      while heartbeats   | 
**               |      received           | Next: "Normal Operation"
**               |                         |  
**               | if no Heartbeats        |  
**               |   for _FIRST_WARNING    |
**               |   seconds               | Next: "First Alarm"
**  -------------+-------------------------+--------------------------------------
**  First Alarm  | RED Heartbeat           | Fade On ~ 1.5sec, fade Off ~ 1.5 sec
**               |                         |  
**               | if Heartbeat received   | Next: "Normal Operation"                        |  
**               |                         |  
**               | if no Heartbeats        |  
**               |   for _LAST_WARNING     |
**               |   seconds               | Next: "Second Alarm"
**  -------------+-------------------------+--------------------------------------
**  Second Alarm | RED Heartbeat           | Fade On ~1 sec, fade Off ~1 sec
**               |                         |  
**               | if Heartbeat received   | Next: "Normal Operation"                        |  
**               |                         |  
**               | if no Heartbeats        |  
**               |   for _MAX_NO_HARTBEAT  |
**               |   seconds               | Next: "Last Change"
**  -------------+-------------------------+--------------------------------------
**  Last Change  | RED blink               | Blink On ~ 100mS, Off ~ 100mS
**               |                         | (duration _LAST_CHANGE seconds)
**               |                         |  
**               | if Heartbeat received   | Next: "Normal Operation"                        |  
**               |                         | 
**               |                         | Next: "Reset Master" state
**  -------------+-------------------------+--------------------------------------
**  Reset Master | WHITE ON                | loop indefinitely...
**               |                         | or Wait for RESET from Master
**  -------------+-------------------------+--------------------------------------
**  
**  TERMS OF USE: MIT License. See bottom of file.
*/

#include "ATtiny85WatchDog.h"

volatile  bool receivedInterrupt = false;
uint8_t   feedsReceived = 0;
uint32_t  loopTimer, lastHartbeatTimer = 0;
uint32_t  waitTimer;

//----------------------------------------------------------------
void interruptSR(void) 
{
  receivedInterrupt = true;
    
}   // interruptSR()

//----------------------------------------------------------------
bool handleInterrupt()
{
  if (receivedInterrupt)
  {
    receivedInterrupt = false;
    lastHartbeatTimer = millis();
    neoPixOn(0, neoPixWhite);
    delay(20);
    return true;
  }
  return false;
  
} //  handleInterrupt()


//----------------------------------------------------------------
void setup() 
{
    //-- INITIALIZE NeoPixel neoPixel object (REQUIRED)
    //neoPixel.begin();    
    //-- with tinyNeoPixel_Static, you need to set pinMode yourself. This means 
    //-- you can eliminate pinMode() and replace with direct port writes to 
    //-- save a couple hundred bytes in sketch size (note that this
    //-- savings is only present when you eliminate *all* references to pinMode).
    //-- leds.begin() not needed on tinyNeoPixel_Static     
    pinMode(_PIN_NEOPIXELS, OUTPUT);
    //--Turn OFF all pixels ASAP  
    //neoPixel.clear();
    //neoPixel.show();            
    //neoPixel.setBrightness(_NEO_BRIGHTNESS);
    neoPixel.begin();
    neoPixel.setBrightness(_NEO_BRIGHTNESS);
    neoPixel.show(); // Initialize all pixels to 'off'

    pinMode(_PIN_HEARTBEAT, INPUT); 
    
    digitalWrite(_PIN_RESET_MYSELF, HIGH);
    pinMode(_PIN_RESET_MYSELF,  OUTPUT); 
    digitalWrite(_PIN_RESET_MYSELF, HIGH);

    enableInterrupt(_PIN_HEARTBEAT, interruptSR, CHANGE);

    waitTimer = millis();
    while((millis() - waitTimer) < _STARTUP_TIME)
    {
      neoPixHeartBeat(0, 12000, neoPixBlue, neoPixFade);
    }
    neoPixOff(0);

    receivedInterrupt = false;
    feedsReceived     = 0;
    lastHartbeatTimer = millis();

} // setup()
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

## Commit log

2022-12-31 31-12-2022 Release Candidate
    [DSMRloggerESP32.scad, DSMRloggerESP32.stl, FTDIbox.scad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]
2023-01-13 3Dfiles updated
    [DSMR32_Bottom_R50.stl, DSMR32_R50.scad, DSMR32_Top_R50_35_Oled.stl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]
2023-01-30 30-01-2023 minor fixes and 3Dfiles
    [DSMR32_Bottom_R50.stl, DSMR32_R50.scad, DSMR32_Top_R50_09_Oled.stl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]
2023-01-30 30-01-2023 3Dfilesi/DSMR32_R50.scad
    [DSMR32_R50.scad]
2023-01-30 30-01-2023 3Dfiles/DSMR32_R50.scad
    [DSMR32_R50.scad]
2023-02-25 v5.0.5 can run as AccessPoint
    [DSMR32_R50.scad, DSMR32_R50_v18.scad, oled09Stand.stl]
2023-03-01 Arduino ESP32 Core 2.0.7
2023-03-31 31-03-2023 Update 3D files
    [DSMR-logger32_R50_v19.scad, DSMR-logger32_R50_v19.stl, DSMR-logger32_R52_v19.scad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]
2023-04-01 April Fool's release
    [DSMR-logger32_R52_v19.scad, DSMR-logger32_R52_v19.stl]
2023-04-24 3D files
    [DSMR-logger32_R50_v19.scad, DSMR-logger32_R52_v19.scad, DSMR-logger32_R52_v19.stl]
2023-04-25 Minor changes 3D files
    [DSMR-logger32_R52_v19.scad, DSMR-logger32_R52_v19.stl]
2023-05-27 small bug fixes and 3Dfiles Rev.2.0
    [DSMR-logger32_R52_v20.scad]
2023-10-19 add build map
    [DSMR-logger32_R52_v20.scad]
2024-01-02 Updated 3D files to YAPPgenerator v3.0
    [DSMR-logger32_R50_v19.scad, DSMR-logger32_R50_v19.stl, DSMR-logger32_R52_v19.scad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]
2024-01-03 Added STL files
    [DSMR-logger32_R52_09_v30.stl, DSMR-logger32_R52_Base_v30.stl, DSMR-logger32_R52_SwitchExtenders_v30.stl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]
2024-01-03 Removed old STL files
    [DSMR-logger32_R52_09_v30.stl, DSMR32_Bottom_R50.stl, DSMR32_Top_R50_09_Oled.stl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]
2024-02-23 Re-aranged 3Dfiles directory
    [DSMR-logger32_R52_Base_v30.stl, DSMR-logger32_R52_Stand_O09_v30.stl, DSMR-logger32_R52_Stand_O13_v30.stl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]
2024-09-07 Convert to PlatformIO First error free compile (#1)
    [DSMRlogger32.cpp, DSMRsetupStuff.cpp, FSYSstuff.cpp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]
2024-09-11 Cleaneup "arduinoGlue" and removed all commented by convertor in other files (#3)
2024-09-11 BUGFIX not getting any data from slimmemMeter (doSystemTask())
    [DSMRlogger32.cpp]
2024-09-16 Shield code fine tuning
    [partitions32.csv]
2024-09-17 Changed some Shield32 values and resetWifi in menuStuff (#6)
    [DSMRindex.js, DSMRlogger32.cpp, Shield32.cpp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]
2024-09-25 Create Upgrade_v5.2.9 folder and python program (#11)
    [partitions32.csv]
2024-09-25 Nu de goede versie
2024-09-29 BUG [Upload] file with no selection crashes the FileSystem (#12)
    [DSMRlogger32.cpp, FSmanager.cpp]
2024-10-01 Add power Bars to GUI (#13)
    * Added Gauges
    * Werkende versie van de Power Bars
    * Relay State in nav-bar
2024-10-15 Refactoring Shield with One Relay
2024-10-15 Add second relay and changed logic and presentation (#15)
2024-10-16 Local Update Bug (#16)
    [DSMRlogger32.cpp, FSmanager.cpp, UpdateManager.cpp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]
2024-10-16 devInfo nu ook Shield Relay2
2024-10-17 Update restAPI.cpp
    Change doc[‘devinfo’] to doc[“devinfo”]
2025-08-17 Better error handling in FSmanager (#19)
    [DSMRlogger32.cpp, FSmanager.cpp]
2026-02-25 prepare for flasher.aandewiel.nl
    [partitions32.csv]
